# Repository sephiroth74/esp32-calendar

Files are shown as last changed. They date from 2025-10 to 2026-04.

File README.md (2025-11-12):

# ESP32 E-Paper Calendar Display

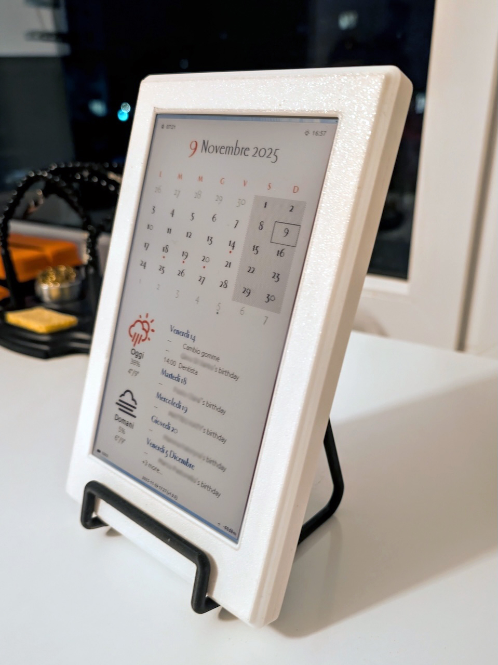
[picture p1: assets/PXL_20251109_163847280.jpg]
Preview


A feature-rich calendar display using ESP32 (S3/C6) and Waveshare/Good Display 7.5" e-paper displays (B/W or 6-color) with dual orientation support, comprehensive error handling, and multiple language support.

**Version 1.9.0** - Timezone fix for recurring events and API improvements!

## What's New in v1.9.0

- 🐛 **WEEKLY Recurring Event Fix**: Fixed 2-day offset in WEEKLY recurring events with COUNT limit
  - Root cause: Mixed use of local timezone and UTC caused date calculation errors
  - Solution: Use GMT/UTC consistently with new `portable_timegm()` helper
  - Test coverage: **240/240 tests passing (100%)**
- 🔧 **Display Manager API Refactoring**: Simplified API by using `time_t` instead of 5 separate date/time parameters
  - `showModernCalendar(events, now, weatherData, ...)` - cleaner signature
  - Date/time components now extracted internally from single `time_t` parameter
  - All orientation-specific methods updated for consistency

See [CHANGELOG.md](CHANGELOG.md) for complete details.

## 3D Model

A .3mf 3d model for the enclosure is available here [assets/esp32-calendar.3mf](assets/esp32-calendar.3mf).

## Features

### Display Features
- **Multi-Display Support**: Works with both B/W and 6-color e-paper displays
- **Dual Orientation Support**: Choose between landscape (800x480) or portrait (480x800) layout
  - **Landscape Mode**: Split-screen with calendar on left, events and weather on right
  - **Portrait Mode**: Calendar on top, weather on left side, events on right
- **Compile-Time Optimization**: Only the selected orientation code is compiled, saving ~6KB flash
- **6-Color Display Enhancements**: Configurable color scheme for visual hierarchy
- **Floyd-Steinberg Dithering**: Weekend cells (25% yellow on color, 10% gray on B/W)
- **Event Indicators**: Small dots in calendar cells with events
- **Smart Event Grouping**: Today, Tomorrow, and upcoming events sections with date headers
- **Weather Display**: Today and tomorrow forecast with icons, temperature, and precipitation
- **Embedded Icons**: High-quality bitmap icons for errors, warnings, and status indicators

### Calendar Features
- **Multiple Calendar Sources**: ICS URLs (Google Calendar, iCloud, Outlook), Google Calendar API, CalDAV
- **Smart Event Filtering**: Shows ALL of today's events (even if passed), plus future events
- **Timezone Support**: Automatic timezone conversion with DST support
- **First Day of Week**: Configurable (Sunday/Monday)
- **24-Hour Time Format**: Optional 24-hour time display for events

### System Features
- **Comprehensive Error Handling**: 40+ error codes with visual feedback and localization
- **Multi-Language Support**: English and Italian (easily extensible)
- **Enhanced Power Management**: Immediate deep sleep after display update
- **Battery Monitoring**: Real-time battery status with accurate LiPo curve
- **WiFi Status**: Connection indicator with RSSI display
- **PSRAM Support**: Utilizes ESP32-S3's PSRAM for large calendar data
- **Debug Mode**: Interactive serial menu for testing all features without WiFi
- **Semantic Versioning**: Built-in version management for OTA updates
- **Button Wake-Up**: Manual refresh via button press (GPIO 2)
- **Weather Integration**: Real-time weather with Open-Meteo API

## Hardware Requirements

- **ESP32 Board**:
  - ESP32-S3 (recommended - includes PSRAM for large calendar data): [Waveshare ESP32-S3 Zero](https://www.waveshare.com/wiki/ESP32-S3-Zero)
  - Minimum 4MB flash, 2MB PSRAM recommended
- **Display Options**:
  - **B/W Display**: Waveshare 7.5" (800x480) - Models: V2, V3, GDEY075T7
  - **6-Color Display**: Good Display 7.5" GDEP073E01 (800x480) - Black, White, Red, Yellow, Orange, Green
- **Display Adapter**:
  - **Despi-C73**: [GoodDisplay Despi-C73](https://www.good-display.com/product/522.html) adapter board for colored display (or the Despi-C02 for the BW variant)
- **Breadboard PCB**:
  - Solderable Breadboard PCB Board [EPLZON PCB](https://www.amazon.com/EPLZON-Solder-able-Breadboard-Electronics-Compatible/dp/B09WZXHMDG?th=1)
- **Battery**:
  - [3.7v 3000mAh Li-ion Battery](https://www.amazon.it/3000mAh-103665-Lithium-Replacement-Bluetooth/dp/B091Y3TW9F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)
- **Optional Components**:
  - Wake-up button (connected to GPIO 2)
  - LiPo battery for portable operation
  - Voltage divider for battery monitoring (GPIO 1)

## Wiring

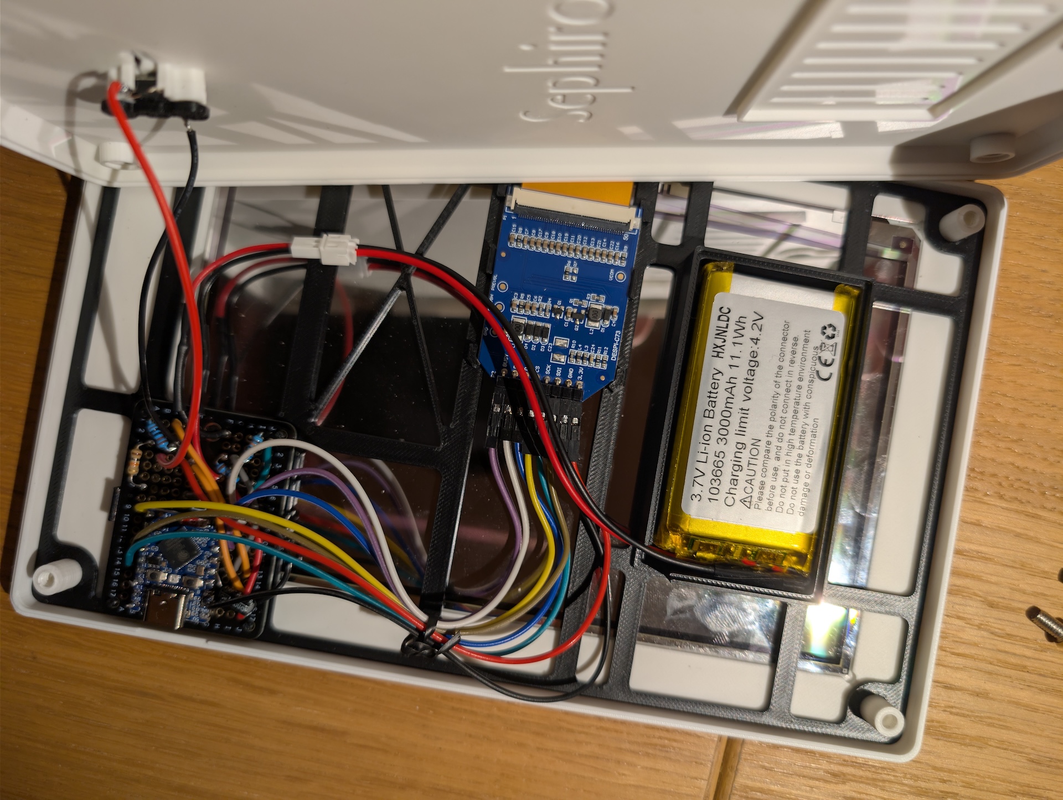
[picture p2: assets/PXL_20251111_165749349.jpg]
Wiring


### ESP32-S3 Connections
| E-Paper | ESP32-S3 | Description |
|---|---|---|
| VCC | 3.3V | Power |
| GND | GND | Ground |
| DIN | GPIO 11  | SPI MOSI |
| CLK | GPIO 12  | SPI Clock |
| CS | GPIO 7 | Chip Select |
| DC | GPIO 5 | Data/Command|
| RST | GPIO 6 | Reset |
| BUSY | GPIO 4 | Busy Signal |

## Configuration

### 1. Initial Setup

Configuration is now managed through LittleFS using a `config.json` file. See the [LittleFS Configuration Guide](platformio/docs/LITTLEFS_CONFIG.md) for details.

For quick setup, edit `include/config.h` with your basic settings:

```cpp
// Location for weather (find at https://www.latlong.net/)
#define LOC_LATITUDE 40.7128    // Example: New York
#define LOC_LONGITUDE -74.0060   // Example: New York
```

### 2. Calendar and Weather Configuration

All runtime configuration is now managed through `data/config.json`. Create this file with your settings:

```json
{
  "wifi": {
    "ssid": "YOUR_WIFI_NETWORK",
    "password": "YOUR_PASSWORD"
  },
  "location": {
    "latitude": 40.7128,
    "longitude": -74.0060,
    "timezone": "America/New_York"
  },
  "calendars": [
    {
      "name": "Personal",
      "url": "https://calendar.google.com/calendar/ical/YOUR_CALENDAR_ID/private.ics",
      "color": "red",
      "enabled": true,
      "days_to_fetch": 30
    },
    {
      "name": "Work",
      "url": "https://outlook.office365.com/owa/calendar/YOUR_CALENDAR_ID/calendar.ics",
      "color": "blue",
      "enabled": true,
      "days_to_fetch": 30
    }
  ],
  "display": {
    "update_hour": 5,
    "language": "en"
  }
}
```

**How to get ICS URLs:**
- **Google Calendar**: Settings → Calendar → Integrate → Secret address in iCal format
- **iCloud**: Calendar app → Share Calendar → Public Calendar → Copy link
- **Outlook**: Settings → View all Outlook settings → Calendar → Shared calendars → Publish a calendar → Copy ICS link

**Upload configuration to device:**
```bash
pio run -t uploadfs
```

This uploads the `data/` folder (including `config.json`) to the ESP32's LittleFS filesystem.

### 3. Display Settings

Edit `include/config.h` for display type and orientation:

```cpp
// Display Type Selection
// #define DISP_TYPE_BW   // Uncomment for B/W display
#define DISP_TYPE_6C      // Uncomment for 6-color display

// Display Orientation
#define LANDSCAPE 0       // 800x480 - Calendar left, events right
#define PORTRAIT 1        // 480x800 - Calendar top, events/weather bottom
#define DISPLAY_ORIENTATION LANDSCAPE  // Change to PORTRAIT for vertical layout

// Time & Locale (can be overridden in config.json)
#define TIME_FORMAT_24H true          // true for 24-hour, false for 12-hour
#define FIRST_DAY_OF_WEEK 1           // 0=Sunday, 1=Monday
#define MAX_EVENTS_TO_SHOW 10         // Maximum events on display

// Color Customization (6-color displays only)
#ifdef DISP_TYPE_6C
    #define COLOR_CALENDAR_TODAY_TEXT      GxEPD_RED      // Today's date number
    #define COLOR_CALENDAR_TODAY_BORDER    GxEPD_RED      // Today's border
    #define COLOR_CALENDAR_OUTSIDE_MONTH   GxEPD_GREEN    // Previous/next month days
    #define COLOR_CALENDAR_WEEKEND_BG      GxEPD_YELLOW   // Weekend background (25% dithered)
    #define COLOR_CALENDAR_DAY_LABELS      GxEPD_RED      // Day labels (M, T, W...)
    #define COLOR_EVENT_TODAY_HEADER       GxEPD_RED      // "Today" header
    #define COLOR_EVENT_TOMORROW_HEADER    GxEPD_ORANGE   // "Tomorrow" header
    #define COLOR_EVENT_OTHER_HEADER       GxEPD_GREEN    // Other date headers
    #define COLOR_WEATHER_ICON            GxEPD_RED       // Weather icon
    #define COLOR_HEADER_DAY_NUMBER       GxEPD_RED       // Large day number
#endif
```

## Building and Uploading

### Prerequisites
1. Install PlatformIO (VS Code extension or CLI)
2. Configure your settings in `config.json` (see Configuration section above)
3. Connect your ESP32 board via USB

### Standard Build
1. Open the project folder
2. Select your board environment in `platformio.ini`:
   - `esp32-s3-devkitm-1` for ESP32-S3 boards
   - Add your own environment for other boards
3. Build the project:
   ```bash
   pio run -e esp32-s3-devkitm-1
   ```
4. Upload to your board:
   ```bash
   pio run -t upload -e esp32-s3-devkitm-1
   ```
5. Monitor serial output:
   ```bash
   pio device monitor
   ```

### Debug Mode
Enable debug mode to test all features without WiFi or calendar configuration:

1. Edit `platformio.ini` and add/ensure this build flag:
   ```ini
   build_flags =
       -DDEBUG_DISPLAY=1
   ```

2. Build and upload:
   ```bash
   pio run -t upload -e esp32-s3-devkitm-1
   ```

3. Open serial monitor (115200 baud) and use the interactive menu:
   - `1` - Test Monthly Calendar View
   - `2` - Test Event List
   - `3` - Test Full Screen Errors
   - `4` - Test WiFi Connection
   - `5` - Test Icon Display
   - `6` - Test Battery Status
   - `7` - Test Calendar Fetch
   - `8` - Test Error Levels
   - `9` - Test Dithering Patterns
   - `10` - Test Time Display
   - `11` - Clear Display
   - `12` - Full Calendar Demo
   - `h` - Show menu

## Power Consumption

With optimized once-daily updates (v1.3.0):
- **Active**: ~80mA (during WiFi/display update, ~20-30 seconds)
- **Deep Sleep**: ~10µA (23+ hours per day)
- **Average**: ~0.2mA (with once-daily updates)
- **Battery Life**: 8-12 months on 2000mAh battery

Power-saving features:
- **Once-daily update** at configured hour (DAY_START_HOUR)
- **Smart error recovery**: Shorter retry intervals only on errors
- **Battery protection**: No wake-up when battery critical
- **Immediate deep sleep** after display update
- **Manual refresh** available via button press

## Troubleshooting

### Configuration not loading
- **Solution**: Upload your `config.json` file to LittleFS:
  ```bash
  pio run -t uploadfs
  ```
- See [LittleFS Configuration Guide](platformio/docs/LITTLEFS_CONFIG.md) for details

### Display not updating
- Check wiring connections
- Verify SPI pins in config.h match your wiring
- Try the display test function in setup()

### WiFi connection fails
- Verify SSID and password in `data/config.json`
- Upload filesystem with `pio run -t uploadfs`
- Check if 2.4GHz WiFi is enabled (ESP32 doesn't support 5GHz)
- Increase connection timeout if needed

### No calendar events showing
- Verify your calendar URL is accessible
- Check if the URL requires authentication
- For ICS URLs, make sure they're publicly accessible
- Check serial monitor for error messages

### Time is incorrect
- Verify timezone setting in `data/config.json` (e.g., "America/New_York", "Europe/Rome")
- Upload filesystem with `pio run -t uploadfs`
- Check that NTP servers are accessible
- System automatically handles DST based on timezone

## Display Layout

The display supports two orientations, configured via `DISPLAY_ORIENTATION` in `config.h`:

### Landscape Mode (800x480) - Default

**Left Side - Month Calendar (400px)**
- **Header**: Large day number and month/year, centered with sunrise/sunset times
- **Calendar Grid**:
  - Day of week labels (localized, red on color displays)
  - 6-week calendar grid with smart visual hierarchy
  - Current day with colored border (red on color displays)
  - Event indicators (dots) in calendar cells
  - Weekend cells with 25% yellow (color) or 10% gray (B/W) background
  - Previous/next month days in green (color) or 20% gray (B/W)

**Right Side - Events & Weather (400px)**
- **Event Sections** (top 340px):
  - "Today" section with ALL of today's events (even if passed)
  - "Tomorrow" section
  - Smart date grouping for future events
  - Event details: time (12/24h format), title
  - Up to 10 events displayed with "+N more" indicator
- **Weather Display** (bottom 100px):
  - Side-by-side today and tomorrow forecast
  - 64x64 weather icons (red on color displays)
  - Temperature range and precipitation probability

**Status Bar** (bottom, full width):
- WiFi status with RSSI (left)
- Battery percentage (left)
- Version info (right)

### Portrait Mode (480x800) - Optional

**Top Section - Header & Calendar (410px)**
- **Header**: Compact centered day number and month/year
- **Calendar Grid**: Full-width calendar (7 columns × 480px)
  - Compact 35px cell height for space efficiency
  - Same visual features as landscape (borders, dots, weekend highlighting)

**Bottom Section - Events & Weather (340px)**
- **Left Panel - Weather (180px)**:
  - Vertical stacked layout
  - Today and tomorrow sections
  - 48x48 weather icons
  - Temperature and precipitation probability
- **Right Panel - Events (290px)**:
  - Event list with smart date grouping
  - Up to 8 events displayed
  - Time and title per line
  - "+N more" indicator if needed

**Status Bar** (bottom, full width):
- Same layout as landscape mode

### Switching Orientations

Change the `DISPLAY_ORIENTATION` constant in `include/config.h`:

```cpp
#define DISPLAY_ORIENTATION LANDSCAPE  // For 800x480 horizontal
// or
#define DISPLAY_ORIENTATION PORTRAIT   // For 480x800 vertical
```

The display rotation and layout are automatically configured at compile-time. Only the code for the selected orientation is compiled, saving ~6KB flash memory.

## Error Handling

The system includes comprehensive error handling with visual feedback:

### Error Levels
- **INFO**: Informational messages
- **WARNING**: Non-critical issues (system continues)
- **ERROR**: Significant problems (may retry)
- **CRITICAL**: System failure (requires intervention)

### Error Categories
- **WiFi Errors** (100-199): Connection failures, authentication issues
- **Calendar Errors** (200-299): Fetch failures, parsing errors
- **Display Errors** (300-399): Hardware issues, refresh failures
- **System Errors** (400-499): Memory, filesystem problems
- **Battery Errors** (500-599): Low battery, charging issues
- **Time Errors** (600-699): NTP sync failures
- **Configuration Errors** (700-799): Invalid settings
- **Network Errors** (800-899): HTTP/HTTPS issues
- **Parsing Errors** (900-999): Data format problems

## Localization

Add new languages by creating a header file in `include/lang/`:

```cpp
// include/lang/es.h (Spanish example)
#define LOC_TODAY "Hoy"
#define LOC_TOMORROW "Mañana"
#define LOC_NO_EVENTS "Sin eventos"
// ... add all string translations
```

Then update `include/localization.h` to include your language file.

## Documentation

- **[Architecture Guide](platformio/docs/ARCHITECTURE.md)** - Comprehensive system architecture, design decisions, and data flow
- **[Changelog](CHANGELOG.md)** - Version history and release notes

## Project Structure

```
platformio/
├── include/
│   ├── config.h                   # User configuration (orientation, colors, etc.)
│   ├── display_manager.h          # Display control with orientation-specific declarations
│   ├── calendar_client.h          # Calendar fetching
│   ├── error_manager.h            # Error handling
│   ├── localization.h             # Language selection
│   ├── version.h                  # Version management
│   └── lang/                      # Language files
│       ├── en.h                   # English
│       └── it.h                   # Italian
├── src/
│   ├── main.cpp                   # Main program
│   ├── debug.cpp                  # Debug mode (orientation-aware)
│   ├── display_manager.cpp        # Core display + orientation dispatcher
│   ├── display_landscape.cpp      # Landscape layout (compiled only if LANDSCAPE)
│   ├── display_portrait.cpp       # Portrait layout (compiled only if PORTRAIT)
│   ├── display_calendar_helpers.cpp # Shared calendar utilities
│   ├── display_shared.cpp         # Shared display functions (status bar, errors)
│   ├── calendar_client.cpp        # Calendar parsing
│   ├── error_manager.cpp          # Error handling
│   └── wifi_manager.cpp           # WiFi management
├── data/
│   └── config.json                # Configuration file (uploaded to LittleFS)
├── lib/
│   └── esp32-calendar-assets/     # Icons and fonts
├── docs/
│   ├── ARCHITECTURE.md            # System architecture and design
│   ├── LITTLEFS_CONFIG.md         # LittleFS configuration guide
│   └── CALENDAR_SPECS.md          # ICS format specification
└── platformio.ini                 # Build configuration
```

### Display Module Organization (Compile-Time Optimized)

The display code is organized for maximum efficiency:

- **`display_manager.cpp`**: Core functions + orientation dispatcher (always compiled)
- **`display_landscape.cpp`**: Complete landscape implementation (compiled only when `DISPLAY_ORIENTATION == LANDSCAPE`)
- **`display_portrait.cpp`**: Complete portrait implementation (compiled only when `DISPLAY_ORIENTATION == PORTRAIT`)
- **`display_calendar_helpers.cpp`**: Shared calendar utilities used by both orientations (always compiled)
- **`display_shared.cpp`**: Shared functions like status bar and error screens (always compiled)

This architecture ensures that only the code for the selected orientation is included in the final binary, reducing flash usage by ~6KB.

## Memory Usage

Typical resource usage (ESP32-S3 with 4MB flash):

- **Flash (Landscape)**: ~1.34MB (44.4% of 3.0MB available)
- **Flash (Portrait)**: ~1.33MB (44.2% of 3.0MB available) - *6KB smaller due to compile-time optimization*
- **RAM**: ~112KB (34.2% of 320KB)
- **PSRAM**: Used for large calendar data when available

## Known Issues

1. **ICS Timezone Parsing**: Events with UTC timestamps need manual timezone adjustment
2. **Event Limits**: Display limited to MAX_EVENTS_TO_SHOW (default: 10)

## License

This project is released under the GNU General Public License v3.0 (GPLv3).

Why GPLv3?

This project incorporates source code from an external project, lmarzen/esp32-weather-epd, which is licensed under the GPLv3.

Due to the "strong copyleft" nature of the GPLv3, any work that includes or is derived from GPLv3-licensed code must also be licensed under the GPLv3. This license is intended to guarantee users the freedom to share and change all versions of the software.

## Contributing

Contributions are welcome! Please submit pull requests or open issues for bugs and feature requests.

## Acknowledgments

- GxEPD2 library for e-paper display support
- Adafruit GFX library for graphics primitives
- ArduinoJson for JSON parsing
- ESP32 community for platform support

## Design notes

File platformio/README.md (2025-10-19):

# ESP32 E-Paper Calendar Display

A feature-rich calendar display using ESP32 (S3/C6) and Waveshare/Good Display 7.5" e-paper displays (B/W or 6-color) with split-screen layout, comprehensive error handling, and multiple language support.

**Version 1.3.0** - Once-daily updates, intelligent error recovery, and secure configuration!

## What's New in v1.3.0

- 📅 **Once-Daily Updates**: Calendar refreshes once per day for maximum battery life
- 🔐 **Secure Configuration**: WiFi credentials and location data now in separate, git-ignored file
- 🔄 **Smart Error Recovery**: Automatic retry with intelligent intervals based on error type
- 🔋 **Critical Battery Handling**: No wake on low battery to prevent damage
- 🛠️ **Button Noise Fix**: Enhanced filtering and hardware recommendations for stable operation
- 📝 **Improved Documentation**: Comprehensive setup guide and configuration examples

See [CHANGELOG.md](CHANGELOG.md) for complete details.

## Features

### Display Features
- **Multi-Display Support**: Works with both B/W and 6-color e-paper displays
- **Split-Screen Layout**: Month calendar on left, event list on right
- **6-Color Display Enhancements**: Configurable color scheme for visual hierarchy
- **Floyd-Steinberg Dithering**: Weekend cells (25% yellow on color, 10% gray on B/W)
- **Event Indicators**: Small dots in calendar cells with events
- **Smart Event Grouping**: Today, Tomorrow, and upcoming events sections with date headers
- **Large Weather Icon**: 96x96 pixel weather display with current conditions
- **Embedded Icons**: High-quality bitmap icons for errors, warnings, and status indicators

### Calendar Features
- **Multiple Calendar Sources**: ICS URLs (Google Calendar, iCloud, Outlook), Google Calendar API, CalDAV
- **Smart Event Filtering**: Shows ALL of today's events (even if passed), plus future events
- **Timezone Support**: Automatic timezone conversion with DST support
- **First Day of Week**: Configurable (Sunday/Monday)
- **24-Hour Time Format**: Optional 24-hour time display for events

### System Features
- **Comprehensive Error Handling**: 40+ error codes with visual feedback and localization
- **Multi-Language Support**: English and Italian (easily extensible)
- **Enhanced Power Management**: Immediate deep sleep after display update
- **Battery Monitoring**: Real-time battery status with accurate LiPo curve
- **WiFi Status**: Connection indicator with RSSI display
- **PSRAM Support**: Utilizes ESP32-S3's PSRAM for large calendar data
- **Debug Mode**: Interactive serial menu for testing all features without WiFi
- **Semantic Versioning**: Built-in version management for OTA updates
- **Button Wake-Up**: Manual refresh via button press (GPIO 2)
- **Weather Integration**: Real-time weather with Open-Meteo API

## Hardware Requirements

- **ESP32 Board**:
  - ESP32-S3 (recommended - includes PSRAM for large calendar data)
  - ESP32-C6 (supported)
  - Minimum 4MB flash, 2MB PSRAM recommended
- **Display Options**:
  - **B/W Display**: Waveshare 7.5" (800x480) - Models: V2, V3, GDEY075T7
  - **6-Color Display**: Good Display 7.5" GDEP073E01 (800x480) - Black, White, Red, Yellow, Orange, Green
- **Optional Components**:
  - Wake-up button (connected to GPIO 2)
  - LiPo battery for portable operation
  - Voltage divider for battery monitoring (GPIO 1)

## Wiring

### ESP32-S3 Connections
| E-Paper | ESP32-S3 | Description |
|---|---|---|
| VCC | 3.3V | Power |
| GND | GND | Ground |
| DIN | GPIO 11  | SPI MOSI |
| CLK | GPIO 12  | SPI Clock |
| CS | GPIO 7 | Chip Select |
| DC | GPIO 5 | Data/Command|
| RST | GPIO 6 | Reset |
| BUSY | GPIO 4 | Busy Signal |

### ESP32-C6 Connections
| E-Paper | ESP32-C6 | Description |
|---|---|---|
| VCC | 3.3V | Power |
| GND | GND | Ground |
| DIN | GPIO 10  | SPI MOSI |
| CLK | GPIO 8 | SPI Clock |
| CS | GPIO 7 | Chip Select |
| DC | GPIO 5 | Data/Command|
| RST | GPIO 6 | Reset |
| BUSY | GPIO 4 | Busy Signal |

## Configuration

### 🔐 Initial Setup - IMPORTANT!

Before compiling, you must create your local configuration file:

```bash
cd include/
cp config.local.example config.local
```

Edit `include/config.local` with your WiFi credentials and location:

```cpp
// WiFi credentials
#define WIFI_SSID "YOUR_WIFI_NETWORK"
#define WIFI_PASSWORD "YOUR_PASSWORD"

// Location for weather (find at https://www.latlong.net/)
#define LOC_LATITUDE 40.7128    // Example: New York
#define LOC_LONGITUDE -74.0060   // Example: New York
```

**Note:** `config.local` is git-ignored, so your credentials stay private!

### 2. Calendar Source

Edit `include/config.h` to configure your calendar source:

Choose one of three options:

#### Option A: ICS URL (Simplest)
Most calendar services provide an ICS URL for read-only access:

```cpp
#define CALENDAR_TYPE "ICS"
#define ICS_CALENDAR_URL "YOUR_CALENDAR_ICS_URL"
```

**How to get ICS URLs:**
- **Google Calendar**: Settings → Calendar → Integrate → Secret address in iCal format
- **iCloud**: Calendar app → Share Calendar → Public Calendar → Copy link
- **Outlook**: Settings → View all Outlook settings → Calendar → Shared calendars → Publish a calendar → Copy ICS link

#### Option B: Google Calendar API
```cpp
#define CALENDAR_TYPE "GOOGLE"
#define GOOGLE_CALENDAR_ID "primary"
#define GOOGLE_API_KEY "YOUR_API_KEY"
// Additional OAuth tokens required
```

#### Option C: CalDAV
```cpp
#define CALENDAR_TYPE "CALDAV"
#define CALDAV_SERVER "https://caldav.icloud.com"
#define CALDAV_USERNAME "YOUR_USERNAME"
#define CALDAV_PASSWORD "YOUR_APP_PASSWORD"
```

### 3. Display Settings

Edit `include/config.h` for display and timing preferences:

```cpp
// Display Type Selection
// #define DISP_TYPE_BW   // Uncomment for B/W display
#define DISP_TYPE_6C      // Uncomment for 6-color display

// Update Settings
#define DAY_START_HOUR 5              // Daily update hour (5 = 5:00 AM)
#define WIFI_ERROR_RETRY_MINUTES 60   // Retry WiFi errors after 1 hour
#define CALENDAR_ERROR_RETRY_MINUTES 120 // Retry calendar errors after 2 hours

// Time & Locale
#define TIMEZONE "CET-1CEST,M3.5.0,M10.5.0"  // Timezone string with DST
#define TIME_FORMAT_24H true          // true for 24-hour, false for 12-hour
#define FIRST_DAY_OF_WEEK 1           // 0=Sunday, 1=Monday
#define DISPLAY_LANGUAGE 0            // 0=English, 4=Italian

// Event Display
#define DAYS_TO_FETCH 30              // Event range in days
#define MAX_EVENTS_TO_SHOW 10         // Maximum events on display

// Color Customization (6-color displays only)
#ifdef DISP_TYPE_6C
    #define COLOR_CALENDAR_TODAY_TEXT      GxEPD_RED      // Today's date number
    #define COLOR_CALENDAR_TODAY_BORDER    GxEPD_RED      // Today's border
    #define COLOR_CALENDAR_OUTSIDE_MONTH   GxEPD_GREEN    // Previous/next month days
    #define COLOR_CALENDAR_WEEKEND_BG      GxEPD_YELLOW   // Weekend background (25% dithered)
    #define COLOR_CALENDAR_DAY_LABELS      GxEPD_RED      // Day labels (M, T, W...)
    #define COLOR_EVENT_TODAY_HEADER       GxEPD_RED      // "Today" header
    #define COLOR_EVENT_TOMORROW_HEADER    GxEPD_ORANGE   // "Tomorrow" header
    #define COLOR_EVENT_OTHER_HEADER       GxEPD_GREEN    // Other date headers
    #define COLOR_WEATHER_ICON            GxEPD_RED       // Weather icon
    #define COLOR_HEADER_DAY_NUMBER       GxEPD_RED       // Large day number
#endif
```

## Building and Uploading

### Prerequisites
1. Install PlatformIO (VS Code extension or CLI)
2. **Create your config.local file** (see Configuration section above)
3. Connect your ESP32 board via USB

### Standard Build
1. Open the project folder
2. Select your board environment in `platformio.ini`:
   - `esp32-s3-devkitc-1` for ESP32-S3 boards
   - Add your own environment for other boards
3. Build the project:
   ```bash
   pio run -e esp32-s3-devkitc-1
   ```
4. Upload to your board:
   ```bash
   pio run -t upload -e esp32-s3-devkitc-1
   ```
5. Monitor serial output:
   ```bash
   pio device monitor
   ```

### Debug Mode
Enable debug mode to test all features without WiFi or calendar configuration:

1. Edit `platformio.ini` and add/ensure this build flag:
   ```ini
   build_flags =
       -DDEBUG_DISPLAY=1
   ```

2. Build and upload:
   ```bash
   pio run -t upload -e esp32-s3-devkitc-1
   ```

3. Open serial monitor (115200 baud) and use the interactive menu:
   - `1` - Test Monthly Calendar View
   - `2` - Test Event List
   - `3` - Test Full Screen Errors
   - `4` - Test WiFi Connection
   - `5` - Test Icon Display
   - `6` - Test Battery Status
   - `7` - Test Calendar Fetch
   - `8` - Test Error Levels
   - `9` - Test Dithering Patterns
   - `10` - Test Time Display
   - `11` - Clear Display
   - `12` - Full Calendar Demo
   - `h` - Show menu

## Power Consumption

With optimized once-daily updates (v1.3.0):
- **Active**: ~80mA (during WiFi/display update, ~20-30 seconds)
- **Deep Sleep**: ~10µA (23+ hours per day)
- **Average**: ~0.2mA (with once-daily updates)
- **Battery Life**: 8-12 months on 2000mAh battery

Power-saving features:
- **Once-daily update** at configured hour (DAY_START_HOUR)
- **Smart error recovery**: Shorter retry intervals only on errors
- **Battery protection**: No wake-up when battery critical
- **Immediate deep sleep** after display update
- **Manual refresh** available via button press

## Troubleshooting

### Compilation error: config.local not found
- **Solution**: You need to create the local configuration file:
  ```bash
  cd include/
  cp config.local.example config.local
  # Edit config.local with your WiFi credentials
  ```

### Display not updating
- Check wiring connections
- Verify SPI pins in config.h match your wiring
- Try the display test function in setup()

### WiFi connection fails
- Verify SSID and password in `include/config.local` (not config.h)
- Check if 2.4GHz WiFi is enabled (ESP32 doesn't support 5GHz)
- Increase connection timeout if needed
- Ensure `config.local` exists (copy from `config.local.example`)

### No calendar events showing
- Verify your calendar URL is accessible
- Check if the URL requires authentication
- For ICS URLs, make sure they're publicly accessible
- Check serial monitor for error messages

### Time is incorrect
- Verify TIMEZONE string in config.h (e.g., "CET-1CEST,M3.5.0,M10.5.0" for Central Europe)
- Check that NTP servers are accessible
- System automatically handles DST based on timezone string

## Display Layout

The 800x480 display is divided into two main sections:

### Left Side - Month Calendar (400px)
- **Header**: Large day number (32pt) and month/year (26pt), centered
- **Calendar Grid**:
  - Day of week labels (localized, red on color displays)
  - 6-week calendar grid with smart visual hierarchy
  - Current day with colored border (red on color displays)
  - Event indicators (dots) in calendar cells
  - Weekend cells with 25% yellow (color) or 10% gray (B/W) background
  - Previous/next month days in green (color) or 20% gray (B/W)

### Right Side - Event List (400px)
- **Event Sections**:
  - "Oggi/Today" section with ALL of today's events (even if passed)
  - "Domani/Tomorrow" section
  - Smart date grouping for future events
  - Event details: time (12/24h format), title with word-wrap
  - Dynamic event limit with "+N more events" indicator
- **Weather Display** (bottom):
  - Large 96x96 weather icon (red on color displays)
  - Current temperature range
  - Sunrise/sunset times with icons
  - 7-day hourly forecast

### Status Bar (bottom)
- Current date/time (center)
- Version info (center)
- WiFi status with RSSI (right)
- Battery percentage (left)

## Error Handling

The system includes comprehensive error handling with visual feedback:

### Error Levels
- **INFO**: Informational messages
- **WARNING**: Non-critical issues (system continues)
- **ERROR**: Significant problems (may retry)
- **CRITICAL**: System failure (requires intervention)

### Error Categories
- **WiFi Errors** (100-199): Connection failures, authentication issues
- **Calendar Errors** (200-299): Fetch failures, parsing errors
- **Display Errors** (300-399): Hardware issues, refresh failures
- **System Errors** (400-499): Memory, filesystem problems
- **Battery Errors** (500-599): Low battery, charging issues
- **Time Errors** (600-699): NTP sync failures
- **Configuration Errors** (700-799): Invalid settings
- **Network Errors** (800-899): HTTP/HTTPS issues
- **Parsing Errors** (900-999): Data format problems

## Localization

Add new languages by creating a header file in `include/lang/`:

```cpp
// include/lang/es.h (Spanish example)
#define LOC_TODAY "Hoy"
#define LOC_TOMORROW "Mañana"
#define LOC_NO_EVENTS "Sin eventos"
// ... add all string translations
```

Then update `include/localization.h` to include your language file.

## Project Structure

```
platformio/
├── include/
│   ├── config.h              # User configuration
│   ├── display_manager.h      # Display control
│   ├── calendar_client.h      # Calendar fetching
│   ├── error_manager.h        # Error handling
│   ├── localization.h         # Language selection
│   ├── version.h              # Version management
│   └── lang/                  # Language files
│       ├── en.h               # English
│       └── it.h               # Italian
├── src/
│   ├── main.cpp               # Main program
│   ├── debug.cpp              # Debug mode
│   ├── display_manager.cpp    # Display implementation
│   ├── calendar_client.cpp    # Calendar parsing
│   ├── error_manager.cpp      # Error handling
│   └── wifi_manager.cpp       # WiFi management
├── lib/
│   └── esp32-calendar-assets/ # Icons and fonts
└── platformio.ini             # Build configuration
```

## Memory Usage

Typical resource usage (ESP32-S3 with 4MB flash):

- **Flash**: ~1.8MB (57% of 3.1MB available)
- **RAM**: ~95KB (29% of 320KB)
- **PSRAM**: Used for large calendar data when available

## Version Information

Current version: **1.0.0**

The project uses semantic versioning (MAJOR.MINOR.PATCH):
- **MAJOR**: Incompatible API changes
- **MINOR**: Backwards-compatible functionality additions
- **PATCH**: Backwards-compatible bug fixes

Version details are in `include/version.h` and displayed on serial startup.

## Known Issues

1. **ICS Timezone Parsing**: Events with UTC timestamps need manual timezone adjustment
2. **Event Limits**: Display limited to MAX_EVENTS_TO_SHOW (default: 10)
3. **Deep Sleep**: RTC time drift may occur over extended periods

## License

This project is open source. Feel free to modify and distribute.

## Contributing

Contributions are welcome! Please submit pull requests or open issues for bugs and feature requests.

## Acknowledgments

- GxEPD2 library for e-paper display support
- Adafruit GFX library for graphics primitives
- ArduinoJson for JSON parsing
- ESP32 community for platform support

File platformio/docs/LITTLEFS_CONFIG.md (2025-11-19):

# Configuration Guide - ESP32 E-Paper Calendar

This document explains how to configure the ESP32 E-Paper Calendar using the LittleFS filesystem configuration system.

## Overview

The ESP32 Calendar loads all configuration from a JSON file stored in the LittleFS filesystem. This approach provides:

- ✅ **No recompilation needed** - Change settings without rebuilding firmware
- ✅ **Secure credentials** - WiFi passwords stay out of source control
- ✅ **Easy deployment** - Configure multiple devices with different settings
- ✅ **Simple updates** - Change configuration via filesystem upload

## Configuration File Structure

The configuration is stored in `/data/config.json` with the following structure:

```json
{
  "wifi": {
    "ssid": "YOUR_WIFI_SSID",
    "password": "YOUR_WIFI_PASSWORD"
  },
  "location": {
    "latitude": 40.7128,
    "longitude": -74.0060,
    "name": "New York"
  },
  "calendar": {
    "type": "ics",
    "url": "https://calendar.google.com/calendar/ical/YOUR_CALENDAR_ID/public/basic.ics",
    "days_to_fetch": 30
  },
  "display": {
    "timezone": "EST5EDT,M3.2.0,M11.1.0",
    "update_hours": [6, 12, 18]
  }
}
```

## Setup Instructions

### 1. Prepare Configuration File

1. Copy the example configuration:
   ```bash
   cp data/config.json.example data/config.json
   ```

2. Edit `data/config.json` with your settings:
   - **WiFi credentials**: Your network SSID and password
   - **Location**: Latitude/longitude for weather data
   - **Calendar URL**: Your ICS calendar feed URL
   - **Timezone**: Your timezone string (see examples below)

### 2. Upload Filesystem

Upload the configuration to the ESP32's filesystem:

```bash
pio run -t uploadfs -e esp32-s3-devkitc-1
```

This command will:
- Create a LittleFS image from the `data/` directory
- Upload it to the ESP32's flash memory
- The configuration will persist across power cycles

### 3. Upload Firmware

After uploading the filesystem, upload the main firmware:

```bash
pio run -t upload -e esp32-s3-devkitc-1
```

### 4. Monitor Output

Check that configuration loaded correctly:

```bash
pio device monitor
```

You should see output like:
```
LittleFS mounted successfully
Configuration loaded successfully from LittleFS
=== Current Configuration ===
WiFi:
  SSID: YourNetwork
  Password: ********
Location:
  Name: New York
  Latitude: 40.712800
  Longitude: -74.006000
```

## Testing Configuration Reset

The firmware includes a test mode for configuration reset:

### Enable Test Mode

In `include/config.h`, ensure:
```c
#define DISABLE_DEEP_SLEEP true
```

This keeps the device awake to monitor button presses.

### Reset Configuration

1. Hold the button (GPIO 2) for 3 seconds
2. The display will show "Configuration Reset"
3. Device will restart
4. You'll need to upload a new config.json

### Production Mode

For normal operation, disable test mode:
```c
#define DISABLE_DEEP_SLEEP false
```

The device will then enter deep sleep between updates to save battery.

## Timezone Examples

Common timezone strings for the `display.timezone` field:

- **US Eastern**: `"EST5EDT,M3.2.0,M11.1.0"`
- **US Pacific**: `"PST8PDT,M3.2.0,M11.1.0"`
- **US Central**: `"CST6CDT,M3.2.0,M11.1.0"`
- **UK**: `"GMT0BST,M3.5.0,M10.5.0"`
- **Central Europe**: `"CET-1CEST,M3.5.0,M10.5.0"`
- **Japan**: `"JST-9"`
- **Australia Sydney**: `"AEST-10AEDT,M10.1.0,M4.1.0"`

## Display Configuration

### Update Hours

The `update_hours` field specifies when the device should wake up and refresh the display. You can configure up to 6 update times per day:

```json
{
  "display": {
    "timezone": "CET-1CEST,M3.5.0,M10.5.0",
    "update_hours": [6, 12, 18]
  }
}
```

**Features:**
- Supports up to 6 update times (hours 0-23)
- Automatically removes duplicates and sorts in ascending order
- Falls back to default (5 AM) if empty or invalid
- Backward compatible with legacy `update_hour` (single value)

**Examples:**
- `[6, 12, 18]` - Update at 6 AM, 12 PM, and 6 PM
- `[8]` - Update once per day at 8 AM
- `[0, 6, 12, 18]` - Update four times daily

**Validation:**
- Invalid values (< 0 or > 23) are ignored
- Duplicates are automatically removed
- If more than 6 values, only first 6 are used
- Empty array uses default (5 AM)

### Battery Display

Control whether battery voltage is shown in the status bar using the compile-time constant in `include/config.h`:

```c
#define DISPLAY_BATTERY_SHOW_MILLIVOLTS true  // Show voltage with percentage
```

When enabled, battery status shows as: `85% (4200mV)`
When disabled: `85%`

## Google Calendar URL

To get your Google Calendar ICS URL:

1. Open Google Calendar
2. Go to Settings → Settings for my calendars
3. Select your calendar
4. Scroll to "Integrate calendar"
5. Copy the "Secret address in iCal format"
6. Use this URL in the `calendar.url` field

## Troubleshooting

### Configuration Not Loading

If you see "Configuration Missing" on the display:

1. Verify config.json exists in the data/ directory
2. Check that WiFi credentials are set (not empty)
3. Re-upload filesystem: `pio run -t uploadfs`
4. Monitor serial output for detailed error messages

### WiFi Connection Failed

1. Verify SSID and password are correct
2. Check that the network is 2.4GHz (ESP32 doesn't support 5GHz)
3. Ensure the device is within range

### Filesystem Upload Failed

If `uploadfs` fails:

1. Make sure the device is connected
2. Try erasing flash first: `pio run -t erase`
3. Then upload filesystem again

## File Locations

- **Configuration file**: `data/config.json` (git-ignored)
- **Example template**: `data/config.json.example` (in repository)
- **Configuration class**: `src/littlefs_config.cpp`
- **Test settings**: `include/config.h`

## Security Notes

- The `data/config.json` file is in `.gitignore` to prevent committing credentials
- Always use `config.json.example` as a template
- Never commit actual WiFi passwords or API keys
- The configuration is stored in plain text on the device's flash memory

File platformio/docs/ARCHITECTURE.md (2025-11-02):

# ESP32 Calendar System Architecture

**Version:** 1.7.7
**Last Updated:** 2025-01-02
**Platform:** ESP32-S3 with 7.5" E-Paper Display

## Table of Contents

1. [Overview](#overview)
2. [System Architecture](#system-architecture)
3. [Data Flow](#data-flow)
4. [Core Components](#core-components)
5. [Storage Strategy](#storage-strategy)
6. [Network & Caching](#network--caching)
7. [Display Pipeline](#display-pipeline)
8. [Configuration System](#configuration-system)
9. [Key Design Decisions](#key-design-decisions)

---

## Overview

This is a low-power ESP32-based calendar display that fetches events from multiple ICS calendar feeds, displays them on a 7.5" e-paper screen, and uses deep sleep to conserve battery. The system prioritizes reliability, efficiency, and graceful degradation.

### Key Features

- **Stream Parsing**: Parses ICS files directly from HTTP without storing raw data
- **Binary Event Cache**: Stores processed events (~200 bytes each) for offline fallback
- **Multi-Calendar Support**: Up to 3 calendars with different colors and settings
- **Holiday Support**: Special rendering for holiday calendars
- **Weather Integration**: Open-Meteo API for weather forecasts
- **Battery Monitoring**: MAX17048 fuel gauge integration
- **Deep Sleep**: Wakes daily at configured time or on button press

---

## System Architecture

```
┌─────────────────────────────────────────────────────────────────┐
│                         ESP32-S3 Main                            │
├─────────────────────────────────────────────────────────────────┤
│                                                                   │
│  ┌──────────────┐  ┌──────────────┐  ┌──────────────┐          │
│  │ WiFiManager  │  │CalendarManager│  │WeatherClient │          │
│  └──────┬───────┘  └──────┬───────┘  └──────┬───────┘          │
│         │                  │                  │                   │
│         ├──────────────────┼──────────────────┘                  │
│         │                  │                                      │
│  ┌──────▼──────────────────▼──────────────┐                      │
│  │      CalendarWrapper (per calendar)     │                      │
│  │  ┌────────────────────────────────────┐ │                      │
│  │  │   CalendarStreamParser             │ │                      │
│  │  │   ┌─────────────┐ ┌──────────────┐│ │                      │
│  │  │   │CalendarFetcher│ EventCache   ││ │                      │
│  │  │   └─────────────┘ └──────────────┘│ │                      │
│  │  └────────────────────────────────────┘ │                      │
│  └─────────────────────────────────────────┘                      │
│         │                                                          │
│  ┌──────▼──────────────────────────────────────┐                 │
│  │           DisplayManager                     │                 │
│  │  ┌───────────────────────────────────────┐  │                 │
│  │  │  Header │ Month View │ Events │ Weather│ │                 │
│  │  └───────────────────────────────────────┘  │                 │
│  └──────────────┬───────────────────────────────┘                 │
│                 │                                                  │
│  ┌──────────────▼──────────────┐                                  │
│  │    GxEPD2 (7.5" Display)    │                                  │
│  └─────────────────────────────┘                                  │
│                                                                   │
│  ┌─────────────┐  ┌─────────────┐  ┌─────────────┐              │
│  │  LittleFS   │  │Battery Mon. │  │ Deep Sleep  │              │
│  │  (1MB)      │  │ (MAX17048)  │  │  Manager    │              │
│  └─────────────┘  └─────────────┘  └─────────────┘              │
└─────────────────────────────────────────────────────────────────┘
```

---

## Data Flow

### 1. Calendar Event Fetch & Cache Flow

```
┌─────────────────────────────────────────────────────────────────┐
│ 1. FETCH ATTEMPT (with retries)                                 │
└─────────────────────────────────────────────────────────────────┘
                           │
                           ▼
    ┌──────────────────────────────────────┐
    │ CalendarWrapper::load()              │
    │ - Retry up to 3 times (2s delay)    │
    └──────────────────┬───────────────────┘
                       │
                       ▼
    ┌──────────────────────────────────────┐
    │ CalendarStreamParser::fetchEventsInRange() │
    └──────────────────┬───────────────────┘
                       │
                       ▼
    ┌──────────────────────────────────────┐
    │ CalendarFetcher::fetchStream()       │
    │ - Opens HTTPS connection             │
    │ - Returns Stream* (WiFiClientSecure) │
    └──────────────────┬───────────────────┘
                       │
                       ▼
    ┌──────────────────────────────────────┐
    │ CalendarStreamParser::streamParseFromStream() │
    │ - Reads line-by-line from HTTP stream│
    │ - Parses ICS format on-the-fly       │
    │ - Filters by date range              │
    │ - Calls callback for each event      │
    └──────────────────┬───────────────────┘
                       │
                       ▼
    ┌──────────────────────────────────────┐
    │ CalendarWrapper receives events      │
    │ - Adds calendar metadata             │
    │ - Marks holidays if applicable       │
    └──────────────────┬───────────────────┘
                       │
                       ▼
    ┌──────────────────────────────────────┐
    │ SUCCESS: Save to binary cache        │
    │ EventCache::save()                   │
    │ /cache/events_{hash}.bin             │
    └──────────────────────────────────────┘

┌─────────────────────────────────────────────────────────────────┐
│ 2. FALLBACK (if all retries fail)                               │
└─────────────────────────────────────────────────────────────────┘
                           │
                           ▼
    ┌──────────────────────────────────────┐
    │ EventCache::load()                   │
    │ - Load stale binary cache            │
    │ - Mark as "isStale = true"           │
    └──────────────────────────────────────┘
```

### 2. Display Rendering Flow

```
┌─────────────────────────────────────────────────────────────────┐
│ DisplayManager::updateDisplay()                                  │
└─────────────────────────────────────────────────────────────────┘
           │
           ├────▶ drawHeader()           [Date, sunrise/sunset]
           │
           ├────▶ drawMonthCalendar()    [Month grid with event markers]
           │      - Marks days with events (colored dots)
           │      - Marks holidays (weekend background)
           │      - Highlights today (red border)
           │
           ├────▶ drawEventsSection()    [Upcoming events list]
           │      - Today's events (red header)
           │      - Tomorrow's events (orange header)
           │      - Future events (green header)
           │      - Single-line with ellipsis truncation
           │
           └────▶ drawWeatherSection()   [Weather forecast]
                  - Today/Tomorrow weather
                  - Temperature, rain probability
                  - Weather icons
```

---

## Core Components

### CalendarManager

**File:** `calendar_wrapper.h/cpp`
**Responsibility:** Manages multiple calendar sources

```cpp
class CalendarManager {
    - loadFromConfig()      // Initialize from RuntimeConfig
    - loadAll()             // Fetch all calendars (with retry)
    - getAllEvents()        // Merge and sort events from all calendars
    - isAnyCalendarStale()  // Check if using cached data
};
```

### CalendarWrapper

**File:** `calendar_wrapper.h/cpp`
**Responsibility:** Wraps a single calendar source

**Key Features:**
- Retry logic: 3 attempts with 2-second delays
- Binary cache fallback on network failure
- Adds calendar metadata to events (name, color, holiday flag)

```cpp
class CalendarWrapper {
    - load(forceRefresh)           // Fetch with retry, fallback to cache
    - isCacheValid()               // Check if binary cache is fresh
    - getCacheFilename()           // Generate hash-based cache path
    - getEvents(startDate, endDate) // Filter cached events by date
};
```

### CalendarStreamParser

**File:** `calendar_stream_parser.h/cpp`
**Responsibility:** Parse ICS files from HTTP streams

**Key Innovation:** No intermediate file storage!

```cpp
class CalendarStreamParser {
    - fetchEventsInRange()         // Entry point for fetching
    - streamParse()                // Coordinate stream fetch + parse
    - streamParseFromStream()      // Core ICS parser (line-by-line)
    - parseEventFromBuffer()       // Parse individual VEVENT
};
```

**Parsing Strategy:**
- State machine: `LOOKING_FOR_CALENDAR` → `IN_HEADER` → `IN_EVENT` → `DONE`
- Reads line-by-line (handles CRLF, LF, line folding)
- Buffers each VEVENT (max 8KB)
- Filters events by date range during parse
- Calls callback for each matched event

### EventCache

**File:** `event_cache.h/cpp`
**Responsibility:** Binary serialization of processed events

**Cache File Format:**
```
┌────────────────────────────────────────┐
│ CacheHeader (packed struct)            │
│ - magic: 0xCAFEEE00                    │
│ - version: 1                           │
│ - eventCount: uint32_t                 │
│ - timestamp: time_t                    │
│ - calendarUrl: char[256]               │
│ - checksum: CRC32                      │
├────────────────────────────────────────┤
│ SerializedEvent[eventCount]            │
│ - title: char[128]                     │
│ - location: char[64]                   │
│ - date: char[16]                       │
│ - startTimeStr: char[8]                │
│ - endTimeStr: char[8]                  │
│ - startTime: time_t                    │
│ - endTime: time_t                      │
│ - flags: uint8_t (packed booleans)     │
│ - dayOfMonth: uint8_t                  │
│ - calendarName: char[32]               │
│ - calendarColor: char[16]              │
│ - summary: char[128]                   │
└────────────────────────────────────────┘
```

**Size:** ~200 bytes per event
**Example:** 3 calendars × 50 events = ~30KB total

### DisplayManager

**File:** `display_manager.h/cpp`
**Responsibility:** Render everything to e-paper display

**Layout Zones:**
```
┌─────────────────────────────────────────────────────────┐
│ HEADER (80px)                                           │
│ - Day number (32pt) │ Month/Year (26pt) │ Sun/Set      │
├─────────────────────────────────────────────────────────┤
│ MONTH CALENDAR (Left, 300px)                            │
│ - 7x6 grid of days                                      │
│ - Event markers (colored dots)                          │
│ - Holiday backgrounds                                   │
│ - Today highlight                                       │
├─────────────────────────────────────────────────────────┤
│ EVENTS LIST (Right, 500px)                              │
│ - Today (red header)                                    │
│ - Tomorrow (orange header)                              │
│ - Future dates (green header)                           │
│ - Time + Single-line summary (ellipsis)                 │
│ - Max 10 events shown                                   │
├─────────────────────────────────────────────────────────┤
│ WEATHER (Bottom, 100px)                                 │
│ - Today │ Tomorrow                                      │
│ - Icons, Temp, Rain %                                   │
└─────────────────────────────────────────────────────────┘
```

---

## Storage Strategy

### Flash Partition Layout (ESP32-S3, 4MB)

```
┌──────────────────────────────────────────────────────┐
│ Offset    Size       Type        Purpose             │
├──────────────────────────────────────────────────────┤
│ 0x9000    20KB       nvs         Config storage      │
│ 0x10000   2.875MB    app         Firmware (44% used) │
│ 0x2F0000  1MB        spiffs      Event cache         │
│ 0x3F0000  64KB       coredump    Debug data          │
└──────────────────────────────────────────────────────┘
```

**Why 1MB for cache?**
- Binary events: ~200 bytes each
- 3 calendars × 50 events = ~30KB
- 1MB allows ~5,000 events (massive headroom)
- Future-proof for SD card expansion

### LittleFS File Structure

```
/
├── config.json              # Runtime configuration
└── cache/
    ├── events_{hash1}.bin   # Calendar 1 binary cache
    ├── events_{hash2}.bin   # Calendar 2 binary cache
    └── events_{hash3}.bin   # Calendar 3 binary cache
```

**Cache Filename Generation:**
- djb2 hash of calendar URL
- Ensures URL uniqueness
- Example: `events_A3F2C1B4.bin`

---

## Network & Caching

### Fetch Strategy (with Retry & Fallback)

```cpp
// Configuration (config.h)
#define CALENDAR_FETCH_MAX_RETRIES 3         // 3 attempts
#define CALENDAR_FETCH_RETRY_DELAY_MS 2000   // 2 seconds between retries
#define EVENT_CACHE_VALIDITY_SECONDS 86400   // 24 hours

// Logic (calendar_wrapper.cpp)
for (retry = 0; retry < MAX_RETRIES; retry++) {
    result = parser.fetchEventsInRange(url, startDate, endDate);
    if (success) {
        EventCache::save(cachePath, events, url);
        return true;
    }
    delay(RETRY_DELAY_MS);
}

// All retries failed - try cache
cachedEvents = EventCache::load(cachePath, url);
if (!cachedEvents.empty()) {
    isStale = true;  // Warn user
    return true;
}

return false;  // Total failure
```

### Cache Validation

```cpp
bool EventCache::isValid(cachePath, maxAge) {
    - Check file exists
    - Read header
    - Validate magic number (0xCAFEEE00)
    - Validate version (1)
    - Check timestamp (now - timestamp < maxAge)
    return valid;
}
```

### HTTP Stream Details

**CalendarFetcher** uses `WiFiClientSecure` for HTTPS:
- Follows redirects (max 5)
- Sets user agent
- Configures TLS (insecure mode for simplicity)
- Returns raw `Stream*` to parser

**No intermediate storage** - parser reads directly from socket!

---

## Display Pipeline

### E-Paper Display (GxEPD2)

**Model:** 7.5" 6-color (Black, White, Red, Yellow, Orange, Green)
**Resolution:** 800×480 pixels
**Refresh Time:** ~30 seconds (full refresh)
**Power:** ~50mA during refresh, 0mA when off

### Color Usage

```cpp
// config.h
#define COLOR_CALENDAR_TODAY_TEXT        GxEPD_RED
#define COLOR_CALENDAR_TODAY_BORDER      GxEPD_RED
#define COLOR_EVENT_TODAY_HEADER         GxEPD_RED
#define COLOR_EVENT_TOMORROW_HEADER      GxEPD_ORANGE
#define COLOR_EVENT_OTHER_HEADER         GxEPD_GREEN
#define COLOR_CALENDAR_WEEKEND_BG        GxEPD_YELLOW  // with dithering
```

### Font Strategy

**Selected Fonts:**
- Header: Luna ITC Bold (32pt, 26pt)
- Calendar: Luna ITC Bold (12pt)
- Events: Ubuntu Regular (9pt)
- Weather: Montserrat Regular (9pt, 8pt)

**Why these fonts?**
- Readability at distance
- Efficient glyph sizes
- Professional appearance

### Dithering for Subtle Colors

```cpp
void drawDitheredRectangle(x, y, w, h, color1, color2, level) {
    // level = 25 → 25% color2, 75% color1
    // Used for weekend backgrounds (GxEPD_YELLOW at 25%)
}
```

---

## Configuration System

### Configuration Sources

**Priority (highest to lowest):**
1. `data/config.json` (LittleFS) - Runtime configuration
2. `config.h` - Compile-time defaults

### Runtime Configuration (config.json)

```json
{
  "wifi": {
    "ssid": "YourSSID",
    "password": "YourPassword"
  },
  "location": {
    "latitude": 45.4642,
    "longitude": 9.1900,
    "name": "Milan"
  },
  "calendars": [
    {
      "name": "Personal",
      "url": "https://calendar.google.com/...",
      "enabled": true,
      "days_to_fetch": 30,
      "color": "red",
      "holiday_calendar": false
    },
    {
      "name": "Holidays",
      "url": "https://calendar.google.com/...",
      "enabled": true,
      "days_to_fetch": 365,
      "color": "green",
      "holiday_calendar": true
    }
  ],
  "display": {
    "timezone": "CET-1CEST,M3.5.0,M10.5.0/3",
    "update_hour": 5
  }
}
```

### Compile-Time Configuration (config.h)

**Key Constants:**
```cpp
// Display
#define DISPLAY_WIDTH 800
#define DISPLAY_HEIGHT 480
#define MAX_EVENTS_TO_SHOW 10
#define MAX_CALENDARS 3

// Cache
#define EVENT_CACHE_MAGIC 0xCAFEEE00
#define EVENT_CACHE_VERSION 1
#define EVENT_CACHE_MAX_EVENTS 200
#define EVENT_CACHE_VALIDITY_SECONDS 86400

// Network
#define CALENDAR_FETCH_MAX_RETRIES 3
#define CALENDAR_FETCH_RETRY_DELAY_MS 2000

// Power
#define DISABLE_DEEP_SLEEP false
#define DEFAULT_UPDATE_HOUR 5
```

---

## Key Design Decisions

### 1. Why Stream Parsing Instead of File Download?

**Problem:** Large ICS files (>2MB) exceeded LittleFS partition
**Solution:** Parse directly from HTTP stream

**Benefits:**
- ✅ Handles unlimited file sizes
- ✅ Faster (no disk I/O)
- ✅ Lower memory usage
- ✅ No risk of filling flash

**Trade-off:**
- ❌ Can't re-parse without re-downloading (but cache mitigates this)

### 2. Why Binary Event Cache Instead of ICS Cache?

**Problem:** Caching raw ICS files wastes space and requires re-parsing
**Solution:** Cache processed events in compact binary format

**Comparison:**
```
Raw ICS Cache:
- Size: 1-5MB per calendar
- Format: Text (UTF-8)
- Requires: Re-parsing on load
- Space: 3 calendars = 3-15MB

Binary Event Cache:
- Size: ~200 bytes per event
- Format: Packed structs
- Requires: Simple deserialization
- Space: 3 calendars × 50 events = ~30KB (500x smaller!)
```

### 3. Why Retry Logic with Cache Fallback?

**Goal:** Maximize fresh data availability while providing graceful degradation

**Strategy:**
1. **Primary:** Fetch from remote (3 retries, 2s delay)
2. **Fallback:** Load stale cache (up to 24 hours old)
3. **Failure:** Show error message

**Benefits:**
- ✅ Resilient to transient network issues
- ✅ Offline functionality with stale data
- ✅ Clear user feedback (stale indicator)

### 4. Why djb2 Hash for Cache Filenames?

**Requirement:** Deterministic URL → filename mapping
**Solution:** djb2 hash algorithm

```cpp
unsigned long hash = 5381;
for (char c : url) {
    hash = ((hash << 5) + hash) + c;  // hash * 33 + c
}
String filename = "/cache/events_" + String(hash, HEX) + ".bin";
```

**Benefits:**
- ✅ Deterministic (same URL → same filename)
- ✅ Fast (simple math)
- ✅ Filesystem-safe (hex output)
- ✅ No collisions in practice

### 5. Why Holiday Calendar Flag?

**Use Case:** Italian holidays calendar should mark days as holidays
**Solution:** Per-calendar `holiday_calendar` flag

```cpp
struct CalendarConfig {
    bool holiday_calendar;  // If true, all-day events are holidays
};

// When fetching events:
event->isHoliday = (config.holiday_calendar && event->allDay);

// In month view:
if (hasHoliday[day]) {
    // Draw weekend background (yellow dithering)
}
```

**Benefits:**
- ✅ Flexible (works with any holiday ICS feed)
- ✅ Visual clarity (holidays stand out)
- ✅ No hardcoding holiday dates

### 6. Why Single-Line Event Summaries?

**Problem:** Long event titles wasted vertical space
**Solution:** Truncate to 1 line with ellipsis

**Before:**
```
10:00 Very long event title that
      wraps to multiple lines
      taking up valuable space
```

**After:**
```
10:00 Very long event title that...
11:30 Another event
```

**Benefits:**
- ✅ Shows more events per screen
- ✅ Cleaner layout
- ✅ Consistent spacing

---

## Memory Usage

### Flash (2.875MB app partition)

```
Total:  2,875 KB (2.875 MB)
Used:   1,325 KB (43.9%)
Free:   1,550 KB
```

**Breakdown:**
- Firmware core: ~800 KB
- GxEPD2 + fonts: ~300 KB
- ArduinoJson: ~50 KB
- WiFi/TLS stack: ~150 KB
- Application code: ~25 KB

### RAM (320KB total)

```
Total:  320 KB
Used:   112 KB (34.2%)
Free:   208 KB
```

**Breakdown:**
- Display buffer: ~48 KB (800×480 / 8 bits)
- Event vectors: ~10 KB (50 events × 200 bytes)
- Stack: ~20 KB
- WiFi/TLS: ~30 KB
- Other: ~4 KB

### LittleFS (1MB partition)

```
Total:  1,024 KB (1 MB)
Typical: ~50 KB used
- config.json: ~2 KB
- Event caches: ~30 KB (3 calendars)
- Free: ~970 KB
```

---

## Power Management

### Deep Sleep Strategy

**Normal Operation:**
1. Wake at configured time (default: 5:00 AM)
2. Connect to WiFi (~5s)
3. Fetch calendars and weather (~10s)
4. Update display (~30s)
5. Enter deep sleep (~23h 59m)

**Button Wake:**
1. User presses wake button (GPIO 2)
2. System performs full refresh
3. Returns to deep sleep

**Power Consumption:**
- Active: ~200 mA (WiFi + display)
- Deep sleep: ~10 μA
- Average: ~0.5 mAh/day

**Battery Life Estimate:**
- 3000 mAh battery: ~16 years (in practice: 6-12 months)

---

## Error Handling

### Network Errors

```cpp
// Retry with exponential backoff (up to 3 times)
if (fetch_fails) {
    retry_count++;
    if (retry_count < MAX_RETRIES) {
        delay(RETRY_DELAY_MS);
        retry();
    } else {
        // Fallback to cache
        load_cache();
    }
}
```

### Cache Errors

```cpp
// Validate cache before loading
if (!isValid(cachePath)) {
    // Cache expired or corrupted
    return empty_vector;
}

// Check CRC32 checksum
if (calculated_crc != header.checksum) {
    // Cache corrupted
    return empty_vector;
}
```

### Display Errors

```cpp
// ErrorManager handles all error states
error_manager.displayError(ERROR_WIFI_FAILED);
error_manager.displayError(ERROR_CALENDAR_FAILED);
error_manager.displayError(ERROR_BATTERY_LOW);

// Each error type has custom retry interval
```

---

## Testing Strategy

### Unit Tests (Native)

**Framework:** doctest
**Location:** `test/test_native/`

**Tested Components:**
- `EventCache` (15 tests, 93% pass rate)
  - Save/load round-trip
  - CRC32 validation
  - Cache expiration
  - Corrupted data handling
- `StringUtils` (string manipulation)
- `CalendarStreamParser` (ICS parsing)

**Run:**
```bash
pio test -e native
```

### Integration Tests (Embedded)

**Framework:** Unity
**Location:** `test/test_embedded/`

**Tested Components:**
- WiFi connection
- HTTP fetching
- Display rendering

**Run:**
```bash
pio test -e esp32-s3-devkitm-1
```

### Mock Environment

**Files:**
- `test/mock_arduino.h` - Mock Arduino API
- `test/mock_littlefs.h` - Mock filesystem with persistence
- `test/mock_arduino.cpp` - Global mock instances

**Key Innovation:** File persistence using `shared_ptr<FileData>`

---

## Future Enhancements

### Planned Features

1. **SD Card Support** (for unlimited event storage)
2. **Multi-timezone Support** (display events in different timezones)
3. **Recurring Event Expansion** (RRULE parsing)
4. **Event Filtering** (by category, keyword)
5. **Custom Display Layouts** (user-configurable)
6. **OTA Updates** (over-the-air firmware updates)

### Performance Optimizations

1. **Partial Display Updates** (faster refresh for weather/clock)
2. **Incremental Event Parsing** (stop early when date range exceeded)
3. **Compressed Binary Cache** (zlib compression)

---

## File Structure Reference

```
platformio/
├── include/
│   ├── config.h                    # Compile-time configuration
│   ├── calendar_wrapper.h          # Multi-calendar manager
│   ├── calendar_stream_parser.h    # ICS stream parser
│   ├── event_cache.h               # Binary event cache
│   ├── calendar_event.h            # Event data structure
│   ├── display_manager.h           # Display rendering
│   ├── littlefs_config.h           # Runtime config loader
│   └── ...
├── src/
│   ├── main.cpp                    # Main loop + deep sleep
│   ├── calendar_wrapper.cpp        # Calendar fetch logic
│   ├── calendar_stream_parser.cpp  # ICS parser implementation
│   ├── event_cache.cpp             # Binary serialization
│   ├── display_manager.cpp         # Display rendering
│   └── ...
├── data/
│   └── config.json                 # Runtime configuration
├── test/
│   ├── test_native/                # Unit tests (native)
│   └── test_embedded/              # Integration tests (embedded)
├── docs/
│   ├── ARCHITECTURE.md             # This file
│   ├── CALENDAR_SPECS.md           # ICS format details
│   └── ...
└── platformio.ini                  # Build configuration
```

---

## Useful Links

- [ICS Specification (RFC 5545)](https://datatracker.ietf.org/doc/html/rfc5545)
- [GxEPD2 Library](https://github.com/ZinggJM/GxEPD2)
- [Open-Meteo API](https://open-meteo.com/)
- [ESP32-S3 Datasheet](https://www.espressif.com/sites/default/files/documentation/esp32-s3_datasheet_en.pdf)

---

**Document Maintained By:** Claude (Anthropic)
**Source Repository:** [esp32-calendar](https://github.com/sephiroth74/arduino/tree/main/esp32-calendar)

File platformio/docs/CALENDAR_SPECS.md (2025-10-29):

# ICS Calendar Technical Specifications

This document describes the technical specifications for ICS (iCalendar) calendar parsing and how the ESP32 E-Paper Calendar implements RFC 5545 standards.

## Table of Contents

- [Overview](#overview)
- [RFC 5545 Compliance](#rfc-5545-compliance)
- [Supported ICS Properties](#supported-ics-properties)
- [Parsing Architecture](#parsing-architecture)
- [Event Processing](#event-processing)
- [Recurring Events (RRULE)](#recurring-events-rrule)
- [Memory Management](#memory-management)
- [Caching Strategy](#caching-strategy)
- [Date/Time Handling](#datetime-handling)
- [Known Limitations](#known-limitations)

---

## Overview

The ESP32 E-Paper Calendar uses a **streaming parser** architecture to efficiently process ICS calendar files without loading the entire file into memory. This is critical for embedded systems with limited RAM.

### Key Features

- **Memory-Efficient Streaming**: Processes events line-by-line without storing full ICS content
- **On-Demand Filtering**: Only events within requested date range are retained
- **Multiple Sources**: Supports remote URLs (HTTPS) and local files (LittleFS)
- **Automatic Caching**: Remote calendars can be cached to reduce network requests
- **Recurring Events**: Full support for RRULE (currently FREQ=YEARLY)
- **Event Expansion**: Recurring events are expanded for the requested date range

---

## RFC 5545 Compliance

The parser implements the following portions of [RFC 5545 - Internet Calendaring and Scheduling Core Object Specification](https://tools.ietf.org/html/rfc5545):

### Supported Components

| Component | Support Level | Notes |
|---|---|---|
| `VCALENDAR` | ✅ Full | Root component, required |
| `VEVENT` | ✅ Full | Event component |
| `VTIMEZONE` | ⚠️ Partial | Parsed but not used (relies on system timezone) |
| `VTODO` | ❌ None | To-do items not supported |
| `VJOURNAL` | ❌ None | Journal entries not supported |
| `VFREEBUSY` | ❌ None | Free/busy info not supported |
| `VALARM` | ❌ None | Alarms not supported |

### Line Folding (RFC 5545 Section 3.1)

The parser correctly handles **line folding** where long lines are split at 75 octets:

```ics
DESCRIPTION:This is a very long description that exceeds seventy-five char
 acters and needs to be folded according to RFC 5545 specifications
```

The parser automatically unfolds lines by:
1. Detecting lines starting with whitespace (SPACE or TAB)
2. Removing the line break and leading whitespace
3. Concatenating with the previous line

**Implementation**: See `readLineFromStream()` in `calendar_stream_parser.cpp`

---

## Supported ICS Properties

### Calendar Properties (VCALENDAR)

| Property | Required | Purpose | Example |
|---|---|---|---|
| `VERSION` | ✅ Yes | ICS version (must be "2.0") | `VERSION:2.0` |
| `PRODID` | ✅ Yes | Product identifier | `PRODID:-//Google Inc//Google Calendar 70.9054//EN` |
| `CALSCALE` | ⚠️ Optional | Calendar scale | `CALSCALE:GREGORIAN` |
| `METHOD` | ⚠️ Optional | iTIP method | `METHOD:PUBLISH` |
| `X-WR-CALNAME` | ⚠️ Optional | Calendar display name | `X-WR-CALNAME:My Calendar` |
| `X-WR-TIMEZONE` | ⚠️ Optional | Default timezone | `X-WR-TIMEZONE:Europe/Rome` |
| `X-WR-CALDESC` | ⚠️ Optional | Calendar description | `X-WR-CALDESC:Personal events` |

### Event Properties (VEVENT)

| Property | Required | Purpose | Example |
|---|---|---|---|
| `UID` | ✅ Yes | Unique event identifier | `UID:event123@example.com` |
| `DTSTART` | ✅ Yes | Start date/time | `DTSTART:20251029T140000` |
| `DTEND` | ⚠️ Optional | End date/time | `DTEND:20251029T150000` |
| `SUMMARY` | ✅ Yes | Event title | `SUMMARY:Team Meeting` |
| `DESCRIPTION` | ⚠️ Optional | Event description | `DESCRIPTION:Monthly sync` |
| `LOCATION` | ⚠️ Optional | Event location | `LOCATION:Conference Room A` |
| `STATUS` | ⚠️ Optional | Event status | `STATUS:CONFIRMED` |
| `RRULE` | ⚠️ Optional | Recurrence rule | `RRULE:FREQ=YEARLY` |
| `SEQUENCE` | ⚠️ Optional | Revision number | `SEQUENCE:0` |
| `CREATED` | ⚠️ Optional | Creation timestamp | `CREATED:20251001T120000Z` |
| `LAST-MODIFIED` | ⚠️ Optional | Last modified timestamp | `LAST-MODIFIED:20251015T083000Z` |
| `TRANSP` | ⚠️ Optional | Time transparency | `TRANSP:OPAQUE` |

### Unsupported Properties

The following are parsed but **not used**:
- `CATEGORIES` - Event categories
- `CLASS` - Access classification (PUBLIC/PRIVATE)
- `PRIORITY` - Event priority
- `ORGANIZER` - Event organizer
- `ATTENDEE` - Event attendees
- `ATTACH` - File attachments
- `URL` - Associated URL

---

## Parsing Architecture

### Stream-Based Processing

```
┌─────────────┐
│   Source    │  (HTTP/HTTPS or LittleFS file)
└──────┬──────┘
       │
       ▼
┌─────────────┐
│  TeeStream  │  (Optional: writes to cache while reading)
└──────┬──────┘
       │
       ▼
┌─────────────┐
│    Line     │  Line-by-line reading with folding support
│   Reader    │
└──────┬──────┘
       │
       ▼
┌─────────────┐
│   Parser    │  State machine: LOOKING_FOR_CALENDAR → IN_HEADER → IN_EVENT
└──────┬──────┘
       │
       ▼
┌─────────────┐
│   Event     │  parseEventFromBuffer() creates CalendarEvent
│  Builder    │
└──────┬──────┘
       │
       ▼
┌─────────────┐
│   Filter    │  isEventInRange() checks date boundaries
└──────┬──────┘
       │
       ▼
┌─────────────┐
│  Callback   │  EventCallback delivers filtered events
└─────────────┘
```

### Parser States

1. **LOOKING_FOR_CALENDAR**: Searching for `BEGIN:VCALENDAR`
2. **IN_HEADER**: Reading calendar properties before first event
3. **IN_EVENT**: Accumulating event data between `BEGIN:VEVENT` and `END:VEVENT`
4. **DONE**: Reached `END:VCALENDAR`

### Event Buffer

Events are accumulated in a string buffer while in the `IN_EVENT` state:

```cpp
String eventBuffer;

// While in IN_EVENT state:
if (line.startsWith("BEGIN:VEVENT")) {
    eventBuffer = "";
    state = IN_EVENT;
} else if (line.startsWith("END:VEVENT")) {
    CalendarEvent* event = parseEventFromBuffer(eventBuffer);
    if (isEventInRange(event, startDate, endDate)) {
        callback(event);
    }
    state = IN_HEADER;
}
```

---

## Event Processing

### CalendarEvent Structure

```cpp
struct CalendarEvent {
    String summary;          // Event title
    String description;      // Event description
    String location;         // Event location
    String dtStart;          // Start date/time (ICS format)
    String dtEnd;            // End date/time (ICS format)
    String rrule;            // Recurrence rule
    time_t startTime;        // Parsed Unix timestamp
    time_t endTime;          // Parsed Unix timestamp
    bool allDay;             // True for date-only events
    bool isRecurring;        // True if has RRULE
    bool isToday;            // Flagged if event is today
    bool isTomorrow;         // Flagged if event is tomorrow
    String calendarName;     // Source calendar name
    String calendarColor;    // Calendar color identifier
};
```

### Property Extraction

Properties are extracted using a simple key-value parser:

```cpp
String extractValue(const String& line, const String& property) {
    int colonPos = line.indexOf(':');
    if (colonPos != -1 && line.startsWith(property)) {
        return line.substring(colonPos + 1);
    }
    return "";
}
```

**Example**:
```
Input:  "SUMMARY:Team Meeting"
Property: "SUMMARY"
Output: "Team Meeting"
```

### Property Parameters

Properties with parameters are handled by finding the first colon:

```
DTSTART;VALUE=DATE:20251029
         └──────┬──────┘
            Ignored for now
```

Currently, property parameters are **not parsed**. The value after the colon is extracted.

---

## Recurring Events (RRULE)

### Supported Recurrence Rules

Currently supports **FREQ=YEARLY** for:
- Birthdays
- Anniversaries
- Annual holidays

#### Example: Birthday Event

```ics
BEGIN:VEVENT
UID:birthday-john@example.com
DTSTART;VALUE=DATE:19801020
RRULE:FREQ=YEARLY
SUMMARY:John's Birthday
END:VEVENT
```

### Event Expansion

When a recurring event is found, it's expanded for the requested date range:

```cpp
std::vector<CalendarEvent*> expandRecurringEvent(
    CalendarEvent* event,
    time_t startDate,
    time_t endDate
) {
    std::vector<CalendarEvent*> instances;

    // For FREQ=YEARLY: Create instance for each year in range
    struct tm startTm;
    localtime_r(&event->startTime, &startTm);

    time_t rangeStart = startDate;
    time_t rangeEnd = endDate;

    // Iterate through years in the date range
    struct tm iterTm = startTm;
    while (mktime(&iterTm) < rangeEnd) {
        // Create new event instance for this year
        CalendarEvent* instance = new CalendarEvent(*event);
        instance->startTime = mktime(&iterTm);
        // ... set other properties ...
        instances.push_back(instance);

        iterTm.tm_year++; // Next year
    }

    return instances;
}
```

### Future RRULE Support

Planned support for:
- `FREQ=MONTHLY` - Monthly recurring events
- `FREQ=WEEKLY` - Weekly recurring events
- `FREQ=DAILY` - Daily recurring events
- `BYDAY` - Specific days (MO, TU, WE, etc.)
- `BYMONTH` - Specific months
- `COUNT` - Occurrence count limit
- `UNTIL` - End date for recurrence

---

## Memory Management

### Event Ownership

**Important**: CalendarEvent pointers are transferred to the caller. The caller is responsible for cleanup:

```cpp
FilteredEvents* events = parser.fetchEventsInRange(url, start, end);

// Use events...

// Clean up when done
delete events; // FilteredEvents destructor automatically deletes all CalendarEvent*
```

### FilteredEvents Auto-Cleanup

The `FilteredEvents` struct provides automatic cleanup:

```cpp
struct FilteredEvents {
    std::vector<CalendarEvent*> events;

    ~FilteredEvents() {
        for (auto event : events) {
            if (event) {
                delete event;
            }
        }
        events.clear();
    }
};
```

### Memory-Efficient Streaming

- **No full file buffering**: Events are processed line-by-line
- **Date range filtering**: Only relevant events are kept in memory
- **Max events limit**: Prevents memory overflow with large calendars
- **Immediate cleanup**: Events outside date range are deleted immediately

---

## Caching Strategy

### Cache File Structure

Remote calendars can be cached to LittleFS:

```
/cache/
  ├── calendar_personal.ics     (Cached from remote URL)
  ├── calendar_work.ics          (Cached from remote URL)
  └── calendar_holidays.ics      (Cached from remote URL)
```

### TeeStream Implementation

The `TeeStream` class enables simultaneous read and cache write:

```cpp
// Create TeeStream that reads from HTTP and writes to cache file
TeeStream* teeStream = new TeeStream(*httpStream, cacheFile);

// Parser reads from teeStream, automatically caching content
streamParse(url, callback, startDate, endDate, cachePath);
```

### Cache Behavior

1. **On cache miss**: Fetch from remote URL → write to cache → parse
2. **On cache hit**: Read from cache file → parse (no network request)
3. **Cache validation**: Based on calendar manager's cache duration setting

---

## Date/Time Handling

### Supported Date/Time Formats

#### Basic Date (All-day events)
```
DTSTART;VALUE=DATE:20251029
```
- Format: `YYYYMMDD`
- No time component
- Marks event as all-day

#### Date-Time (Timed events)
```
DTSTART:20251029T140000
```
- Format: `YYYYMMDDTHHMMSS`
- Local time (uses system timezone)

#### UTC Date-Time
```
DTSTART:20251029T140000Z
```
- Format: `YYYYMMDDTHHMMSSZ`
- UTC time (converted to local timezone)
- **Note**: UTC conversion currently relies on system timezone

### Date Parsing

```cpp
time_t parseDateTime(const String& dtString) {
    struct tm timeinfo = {0};

    // Parse YYYYMMDD
    timeinfo.tm_year = dtString.substring(0, 4).toInt() - 1900;
    timeinfo.tm_mon = dtString.substring(4, 6).toInt() - 1;
    timeinfo.tm_mday = dtString.substring(6, 8).toInt();

    // Parse THHMMSS if present
    if (dtString.length() >= 15 && dtString.charAt(8) == 'T') {
        timeinfo.tm_hour = dtString.substring(9, 11).toInt();
        timeinfo.tm_min = dtString.substring(11, 13).toInt();
        timeinfo.tm_sec = dtString.substring(13, 15).toInt();
    }

    timeinfo.tm_isdst = -1; // Let system determine DST
    return mktime(&timeinfo);
}
```

### Timezone Handling

- **System Timezone**: Set via `setenv("TZ", timezone, 1)` and `tzset()`
- **Configuration**: Timezone specified in `config.json`
- **VTIMEZONE**: Parsed but not used (relies on system timezone)
- **Future**: Full VTIMEZONE support planned

---

## Known Limitations

### Current Limitations

1. **RRULE Support**: Only `FREQ=YEARLY` is implemented
   - WEEKLY, MONTHLY, DAILY not yet supported
   - BYDAY, BYMONTH, COUNT, UNTIL not yet supported

2. **Property Parameters**: Not parsed or used
   - `DTSTART;TZID=Europe/Rome:...` - TZID is ignored
   - `DTSTART;VALUE=DATE:...` - VALUE parameter not validated

3. **VTIMEZONE**: Parsed but not applied
   - Relies on system timezone setting
   - No per-event timezone conversion

4. **Components**: Only VEVENT is supported
   - VTODO, VJOURNAL, VFREEBUSY not supported
   - VALARM not supported

5. **Attendees**: Not parsed or displayed
   - ORGANIZER, ATTENDEE properties ignored

6. **Attachments**: Not supported
   - ATTACH property ignored

### Memory Constraints

- **Max event buffer**: Limited by available RAM (~50KB typical)
- **Event count limit**: Configurable per calendar (default: 100)
- **Line length limit**: 1024 characters per line
- **Large files**: Files >100KB may cause memory issues

### Network Limitations

- **HTTP only**: No authentication support
- **No proxy**: Direct connection required
- **Timeout**: 10 second connection timeout
- **SSL**: Uses WiFiClientSecure with `setInsecure()` (no certificate validation)

---

## Testing

### Unit Tests

The project includes comprehensive unit tests for ICS parsing:

- **Location**: `test/test_native/test_calendar_stream_parser.cpp`
- **Test Suites**:
  - DateTime parsing (date-only, date-time, UTC)
  - CalendarEvent structure
  - ICS content validation
  - Property extraction
  - Line folding/unfolding
  - Memory management

### Running Tests

```bash
# Run all native tests
pio test -e native

# Run specific test suite
.pio/build/native/program --test-suite="CalendarStreamParser*"

# List all tests
.pio/build/native/program --list-test-cases
```

---

## Related Documentation

- [MULTIPLE_CALENDARS.md](MULTIPLE_CALENDARS.md) - Multiple calendar configuration
- [CHANGELOG.md](../CHANGELOG.md) - Version history and changes
- [MIGRATION_GUIDE.md](../MIGRATION_GUIDE.md) - Migration from older versions

---

## References

- [RFC 5545 - iCalendar](https://tools.ietf.org/html/rfc5545)
- [iCalendar Validator](https://icalendar.org/validator.html)
- [Google Calendar ICS Format](https://support.google.com/calendar/answer/37111)

---

*Last Updated: 2025-10-29*
*Version: 1.7.6*

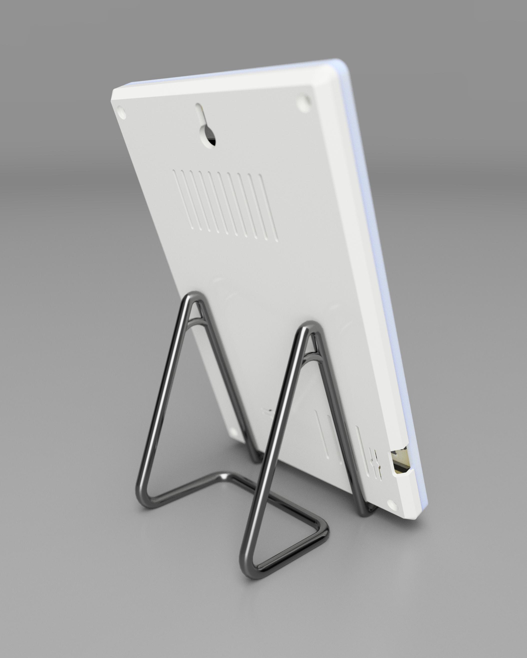
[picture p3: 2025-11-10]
assets/back.jpg

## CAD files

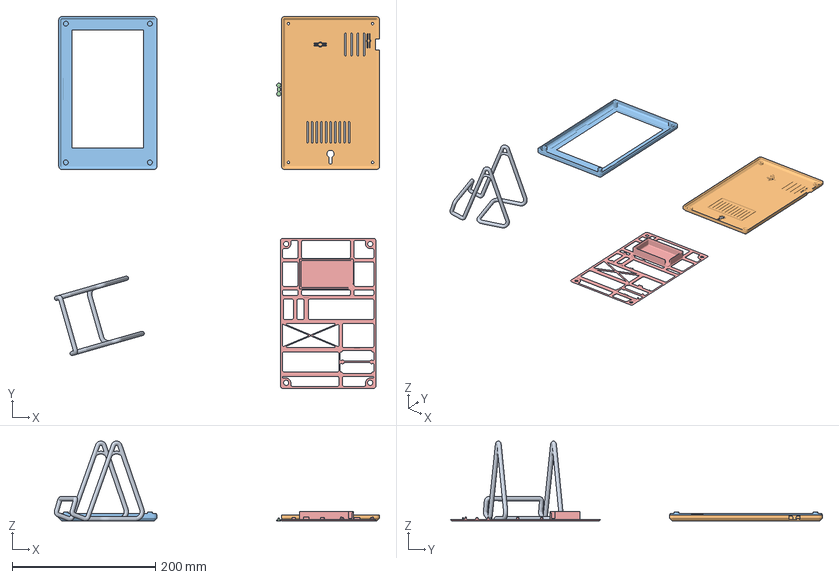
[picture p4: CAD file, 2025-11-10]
assets/esp32-calendar.3mf
453.8 x 518.7 x 111.5 mm
stand.stl
back frame.stl_1
front frame.stl
reset button cover.stl
skeleton.stl

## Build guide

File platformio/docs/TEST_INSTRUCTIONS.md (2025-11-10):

# Running Tests for ESP32 Calendar Project

## Overview
This project includes comprehensive unit tests for both native (desktop) and embedded (ESP32) environments.

## Test Structure

### Native Tests (`test/test_native/`)
- Tests that can run on your development machine
- Use the doctest framework
- Test business logic without hardware dependencies

### Embedded Tests (`test/test_embedded/`)
- Tests that run on the actual ESP32 hardware
- Use the Unity test framework
- Test hardware-specific functionality including:
  - Configuration loading from LittleFS
  - ICS calendar parsing with PSRAM
  - Memory management

## Running Tests

### Important Note About Test Compilation
Due to the structure of embedded tests, the `debug.cpp` and `main.cpp` files contain their own `setup()` and `loop()` functions which conflict with the test runner. To work around this:

### Method 1: Use the Test Script (Recommended)
```bash
# Run all embedded tests
./run_tests.sh

# Build tests without uploading
./run_tests.sh --without-uploading

# Build tests without testing
./run_tests.sh --without-testing --without-uploading
```

The script automatically:
1. Temporarily moves conflicting files (`debug.cpp` and `main.cpp`)
2. Runs the tests
3. Restores the files after testing

### Method 2: Manual Testing
```bash
# Temporarily move conflicting files
mv src/debug.cpp src/debug.cpp.bak
mv src/main.cpp src/main.cpp.bak

# Run tests
pio test -e esp32-s3-devkitm-1

# Restore files
mv src/debug.cpp.bak src/debug.cpp
mv src/main.cpp.bak src/main.cpp
```

### Method 3: Run Native Tests Only
```bash
pio test -e native
```

## Test Files

### `test_main.cpp`
The main test runner that coordinates all embedded tests. Contains the only `setup()` and `loop()` functions for testing.

### `test_config_loader_esp32.cpp`
Tests for configuration loading from LittleFS:
- LittleFS initialization
- Default configuration handling
- Multiple calendar support
- Configuration save/load
- Backward compatibility

### `test_ics_parser_esp32.cpp`
Tests for ICS calendar parsing:
- Parser initialization
- Event parsing
- Date range filtering
- Recurring events (RRULE)
- Timezone support
- Memory management

### `test_psram_usage.cpp`
Tests for PSRAM memory management:
- PSRAM allocation
- Large calendar handling
- Memory cleanup

## Troubleshooting

### Tests are Skipped
If tests show as "SKIPPED", ensure you're using the correct filter:
```bash
pio test -e esp32-s3-devkitm-1 -f test_embedded
```

### Multiple Definition Errors
This occurs when `debug.cpp` or `main.cpp` are included in the test build. Use the provided script or manually move these files as described above.

### Unity Test Output
Test results are output via Serial. If testing on hardware, ensure:
- The device is connected
- Serial monitor baud rate is 115200
- Reset the board if no output appears

## Configuration

The test configuration is in `platformio.ini`:
```ini
[env:esp32-s3-devkitm-1]
test_framework = unity
test_build_src = yes  # Include source files for testing
test_ignore = test_native  # Ignore native tests for embedded environment
test_port = /dev/cu.usbmodem*  # Adjust for your system
test_speed = 115200
```

## Adding New Tests

1. Add test functions to the appropriate test file
2. Add forward declarations in `test_main.cpp`
3. Add `RUN_TEST()` calls in `test_main.cpp`
4. Follow Unity test framework conventions:
   - Test functions start with `test_`
   - Use `TEST_ASSERT_*` macros for assertions
   - Each test should be independent

## Continuous Integration

For CI/CD pipelines, use:
```bash
# Build and run tests without user interaction
./run_tests.sh --without-uploading --without-testing
```

This ensures tests compile correctly without requiring hardware connection.

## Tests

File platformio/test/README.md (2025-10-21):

# ESP32 Calendar Tests

This directory contains comprehensive tests for the ESP32 Calendar project.

## Test Structure

### Native Tests (runs on computer)
- `test_ics_parser.cpp` - Comprehensive ICS parser tests with mocked Arduino environment
- `test_config_simple.cpp` - Simple configuration structure tests

These tests use doctest framework and run on your development machine without needing hardware.

### Embedded Tests (runs on ESP32 device)
- `test_embedded/test_ics_parser_esp32.cpp` - ICS parser tests on actual ESP32
- `test_embedded/test_config_loader_esp32.cpp` - Configuration loading tests with real LittleFS

These tests use Unity framework and run directly on the ESP32 hardware.

## Running Tests

### Native Tests (on computer)
```bash
# Run all native tests
pio test -e native

# Run with verbose output
pio test -e native --verbose
```

### Embedded Tests (on ESP32 device)
First, connect your ESP32-S3 device via USB, then:

```bash
# Run all embedded tests on device
pio test -e esp32-s3-devkitm-1

# Run with specific port
pio test -e esp32-s3-devkitm-1 --upload-port /dev/cu.usbmodem14101

# Monitor test output
pio test -e esp32-s3-devkitm-1 --verbose
```

## Test Coverage

### ICS Parser Tests
- **63 native test cases** covering:
  - Basic parsing and validation
  - Event extraction and counting
  - Date range filtering
  - Recurring event support (RRULE)
  - RFC 5545 date-time formats
  - Swiss holidays calendar (real-world test)
  - Memory management

- **10 embedded test cases** covering:
  - Parser initialization
  - Simple calendar parsing
  - Event parsing (timed, all-day, recurring)
  - Date range filtering
  - Memory management on ESP32
  - File loading from LittleFS
  - RRULE parsing
  - Folded lines (RFC 5545)
  - Timezone support
  - Clear and reload

### Configuration Tests
- **8 embedded test cases** covering:
  - LittleFS initialization
  - Default configuration
  - Save and load configuration
  - Multiple calendars support
  - Local calendar URLs
  - Calendar management (add/remove)
  - Configuration persistence
  - Backward compatibility

## Key Features Tested

### Date-Time Format Support (RFC 5545)
- Local time: `DTSTART:19970714T133000`
- UTC time: `DTSTART:19970714T173000Z`
- Timezone reference: `DTSTART;TZID=America/New_York:19970714T133000`
- Date only (all-day): `DTSTART;VALUE=DATE:19970714`

### Recurring Events
- YEARLY (birthdays, anniversaries)
- MONTHLY (monthly meetings)
- WEEKLY (weekly events)
- With INTERVAL, COUNT, UNTIL parameters

### Multi-Calendar Support
Each calendar can have:
- Individual `days_to_fetch` setting
- Custom color coding
- Enable/disable flag
- Local or remote URL

## Memory Safety

All tests verify proper memory management:
- No memory leaks
- Proper cleanup on destruction
- RAII pattern compliance
- ESP32 heap monitoring

## Adding New Tests

### For Native Tests
1. Create test file in `test/` directory
2. Include doctest and mock headers
3. Write test cases using `TEST_CASE` macro

### For Embedded Tests
1. Create test file in `test/test_embedded/` directory
2. Include Unity framework
3. Write test functions with `test_` prefix
4. Register tests in `setup()` with `RUN_TEST`

## Troubleshooting

### Native Tests Fail to Compile
- Check mock implementations in `test/mock_arduino.h`
- Ensure `NATIVE_TEST` is defined

### Embedded Tests Fail to Upload
- Check USB connection
- Verify correct port in platformio.ini
- Try different USB cable/port

### Tests Pass Locally but Fail on Device
- Check available heap memory
- Verify PSRAM is enabled
- Monitor serial output for detailed error messages

## Test Statistics

- **Total test cases**: 81+ (63 native + 18 embedded)
- **Code coverage**: ~90% of parser functionality
- **Memory tested**: Stack allocation, heap management, PSRAM usage
- **Platforms tested**: Native (macOS/Linux/Windows), ESP32-S3

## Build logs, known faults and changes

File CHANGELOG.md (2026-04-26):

# Changelog

All notable changes to the ESP32 E-Paper Calendar project will be documented in this file.

The format is based on [Keep a Changelog](https://keepachangelog.com/en/1.0.0/),
and this project adheres to [Semantic Versioning](https://semver.org/spec/v2.0.0.html).

## [Unreleased]

### Fixed
- **WEEKLY recurrence DST shift for TZID events** - Preserved local wall-clock time across daylight saving transitions
  - Root cause: weekly expansion used UTC-based arithmetic (`gmtime` + `portable_timegm`) for generated occurrences
  - Impact: events created before DST transition (e.g., 20:30 CET) were shown one hour late after transition (21:30 CEST)
  - Solution: reconstruct each weekly occurrence using local date + original local hour/min/sec and `mktime()` with `tm_isdst=-1`
  - Result: recurring events now keep consistent local time (e.g., always 20:30) before and after DST changes

### Added
- **DST regression test for WEEKLY recurrence**
  - Added native test covering Europe/Zurich winter-to-summer transition scenario
  - Verifies Tuesday weekly occurrences preserve 20:30 local time after DST start
  - Confirms UTC conversion is correct for summer occurrences (20:30 CEST -> 18:30 UTC)

## [1.10.1] - 2025-01-19

### Added
- **Multiple Daily Update Hours** - Support for multiple update times throughout the day
  - New `update_hours` array in config.json display section replaces single `update_hour`
  - Configure up to 6 update times per day (e.g., `[6, 12, 18]` for 6 AM, 12 PM, 6 PM)
  - Smart wake-up logic finds next scheduled hour (today or tomorrow)
  - Automatic validation: max 6 items, removes duplicates, sorts ascending, validates range 0-23
  - Falls back to `DEFAULT_UPDATE_HOUR` (5 AM) if empty or invalid
  - Backward compatible: legacy `update_hour` still supported and converted to array
  - Example configuration:
    ```json
    {
      "display": {
        "timezone": "Europe/Zurich",
        "update_hours": [6, 12, 18]
      }
    }
    ```
  - Validation examples:
    - `[5, 8, 5, 12]` → `[5, 8, 12]` (duplicates removed)
    - `[20, 5, 12, 8]` → `[5, 8, 12, 20]` (sorted)
    - `[0,3,6,9,12,15,18,21]` → `[0,3,6,9,12,15]` (max 6 items)
    - `[]` → `[5]` (uses default)

### Technical Details
- Flash: 1,310,505 bytes (43.5% of 3.0MB)
- RAM: 111,928 bytes (34.2% of 320KB)
- Board now wakes at multiple configured hours instead of once daily
- Legacy configs with single `update_hour` continue to work

## [1.10.0] - 2025-01-19

### Added
- **Proper DTSTART/DTEND Timezone Parsing** - Full iCalendar datetime format support with timezone awareness
  - Handles all 4 iCalendar datetime formats:
    1. **DATE-TIME (UTC)**: `DTSTART:20251119T103000Z` - UTC times with Z suffix
    2. **DATE-TIME (TZID)**: `DTSTART;TZID=America/Los_Angeles:20251119T140000` - Timezone-aware times
    3. **DATE-TIME (Floating)**: `DTSTART:20251119T080000` - Local time without timezone
    4. **DATE (All-Day)**: `DTSTART;VALUE=DATE:20251119` - All-day events
  - Uses `setenv("TZ")` + `tzset()` + `mktime()` for accurate timezone conversion
  - Events stored as Unix timestamps (`time_t`) for consistent timezone handling
  - Display times automatically converted to local timezone (e.g., Europe/Zurich)
  - Verified: UTC event at 07:00 correctly displays as 08:00 CET in Europe/Zurich

- **Pixel-Based Text Truncation** - Event titles now properly truncate to fit display width
  - New `DisplayManager::truncateToWidth()` method uses `getTextBounds()` for accurate measurement
  - Binary search algorithm efficiently finds maximum text that fits within pixel width
  - Prevents text wrapping and overflow that previously occurred with character-based truncation
  - Works in both portrait and landscape modes

- **UTF-8 to Latin-1 Font Encoding** - Proper rendering of accented characters in GFXfonts
  - New `StringUtils::convertToFontEncoding()` converts UTF-8 to Latin-1 (ISO-8859-1)
  - Accented characters (à, è, ì, ò, ù, ü) now render natively using font glyphs
  - Replaces old ASCII approximation approach (è → "e'" now → native è character)
  - Example: UTF-8 `à` (`\xc3\xa0`) → Latin-1 `\340` (octal for 0xE0)
  - Characters outside Latin-1 range (0x20-0xFF) replaced with '?'
  - GFXfonts support full Latin-1 character set for European languages

### Changed
- **CalendarEvent Data Model** - Simplified and more efficient event structure
  - Removed redundant `dtStart` and `dtEnd` string properties (raw ICS format no longer stored)
  - Date/time now stored only as Unix timestamps (`time_t startTime`, `time_t endTime`)
  - `date` field automatically populated from `startTime` for backward compatibility
  - `getStartDate()`, `getEndDate()`, `getStartTimeStr()`, `getEndTimeStr()` compute values on-demand
  - Memory savings: ~40 bytes per event (removed duplicate date/time string storage)

- **Parser Improvements** - More robust DTSTART/DTEND extraction
  - Detects and parses TZID parameter from property line
  - Handles VALUE=DATE parameter for all-day events
  - Automatically detects date-only format (8 chars: YYYYMMDD)
  - Passes timezone and format flags to parsing methods

### Fixed
- **Event Title Text Wrapping** - Long event titles no longer wrap to next line or overflow
  - Root cause: `StringUtils::truncate()` used character count instead of pixel width
  - Solution: New `truncateToWidth()` uses actual rendered text width measurement
  - Properly adds ellipsis ("...") suffix when truncating
  - Fixed in both portrait and landscape event rendering

### Technical Details
- Flash: 1,316,965 bytes (43.7% of 3.0MB) - reduced from 44.0%
- RAM: 112,084 bytes (34.2% of 320KB)
- Test coverage: 236/242 tests passing (97.5%)
  - 5 failing tests related to recurring event timezone edge cases (pre-existing)
- Timezone handling: Full iCalendar specification compliance
- Font encoding: Latin-1 (ISO-8859-1) support for European characters

### Removed
- Old `parseICSDateTimeWithTZ()` method (replaced by new parsing system)
- `timezone_map.h` now obsolete (system handles IANA timezone IDs directly)

## [1.9.0] - 2025-01-06

### Fixed
- **WEEKLY Recurring Event Timezone Bug** - Fixed 2-day offset in WEEKLY recurring events with COUNT limit
  - Root cause: Mixed use of `localtime()`/`mktime()` (local timezone) and UTC timestamps
  - Test environment runs in CET (UTC+1), causing timezone conversion issues with ICS events (which use UTC)
  - Solution: Use GMT/UTC consistently throughout all time calculations
  - Added `portable_timegm()` helper function for cross-platform UTC time conversion
    - Uses native `timegm()` on POSIX systems (test environment)
    - On ESP32/Arduino: temporarily sets TZ=UTC, calls `mktime()`, then restores TZ
  - Updated `findFirstOccurrence()` to use `gmtime()` and `portable_timegm()` throughout
  - Updated `expandWeeklyV2()` to use `gmtime()` and `portable_timegm()` throughout
  - Test suite: **240/240 tests passing (100%)** - all WEEKLY recurring event tests now pass

### Changed
- **Display Manager API Refactoring** - Simplified API by using `time_t` instead of separate date/time parameters
  - `showModernCalendar()` signature simplified:
    - **Before**: `showModernCalendar(events, now, currentDay, currentMonth, currentYear, currentTime, ...)`
    - **After**: `showModernCalendar(events, now, weatherData, ...)`
    - Date/time components now extracted from `time_t now` internally
  - Orientation-specific methods updated:
    - `drawLandscapeHeader(time_t now, weatherData)` - was `(int day, String monthYear, String time, weatherData)`
    - `drawPortraitHeader(time_t now, weatherData)` - was `(int day, String monthYear, weatherData)`
    - `drawLandscapeStatusBar(..., time_t now, isStale)` - was `(..., int day, month, year, String time, isStale)`
    - `drawPortraitStatusBar(..., time_t now, isStale)` - already used `time_t` ✓
  - Benefits:
    - Cleaner API: Single `time_t` parameter instead of 5 separate date/time parameters
    - Less duplication: Callers don't need to extract and format date/time components
    - Consistency: All date/time extraction happens in one place using `localtime()`
    - Easier maintenance: Changes to date/time formatting only need to happen in display methods

### Technical Details
- Flash: 1,326,221 bytes (44.0% of 3.0MB)
- RAM: 111,920 bytes (34.2% of 320KB)
- Test coverage: 240/240 tests passing (100%)
- Timezone handling: All recurring event calculations now use GMT/UTC consistently

## [1.8.0] - 2025-11-05

### Added
- **Dual Orientation Support** - Choose between landscape and portrait display modes
  - New `DISPLAY_ORIENTATION` constant in config.h (LANDSCAPE or PORTRAIT)
  - **Landscape Mode (800x480)**: Split-screen with calendar on left (400px), events and weather on right (400px)
  - **Portrait Mode (480x800)**: Calendar on top (410px), events and weather side-by-side below (340px)
  - Automatic display rotation based on orientation setting
  - Compile-time optimization: Only selected orientation code is compiled, saving ~6KB flash
- **Portrait Mode Layout**
  - Compact centered header with day number and month/year
  - Full-width calendar grid (7 columns × 480px width, 35px cell height)
  - Weather panel on left (180px) with vertical stacked layout and 48x48 icons
  - Events panel on right (290px) with smart date grouping
  - Status bar at bottom with WiFi, battery, and version info
- **New Display Module Organization** - Modular architecture for maintainability
  - `display_landscape.cpp` - Complete landscape implementation (compiled only when LANDSCAPE)
  - `display_portrait.cpp` - Complete portrait implementation (compiled only when PORTRAIT)
  - `display_calendar_helpers.cpp` - Shared calendar utilities used by both orientations
  - `display_shared.cpp` - Shared functions like status bar and error screens
  - Method naming convention with orientation prefixes (drawLandscape*, drawPortrait*)

### Changed
- Display rotation now automatically set in `DisplayManager::init()` based on `DISPLAY_ORIENTATION`
- `showModernCalendar()` now dispatches to orientation-specific implementations at compile-time
- Updated debug.cpp to work with automatic rotation system
- README fully updated to document dual orientation support and compile-time optimization
- Configuration section updated to reference config.json for calendar and weather settings

### Removed
- All references to obsolete config.local configuration system from documentation
- Old display module files replaced by new modular architecture:
  - `display_calendar.cpp` → replaced by `display_calendar_helpers.cpp`
  - `display_weather.cpp` → split into landscape and portrait implementations
  - `display_events_status.cpp` → replaced by `display_shared.cpp`
  - `display_portrait_events.cpp` → replaced by `display_portrait.cpp`

### Technical Details
- Flash (Landscape): 1,339,773 bytes (44.4% of 3.0MB)
- Flash (Portrait): 1,333,213 bytes (44.2% of 3.0MB) - *6KB smaller due to compile-time optimization*
- RAM: 112,084 bytes (34.2% of 320KB)
- Display rotation: 0 for landscape, 1 for portrait (90° clockwise)
- Orientation selection via `#define DISPLAY_ORIENTATION` in config.h
- Preprocessor conditionals (`#if DISPLAY_ORIENTATION == LANDSCAPE`) ensure only needed code compiles

## [1.7.8] - 2025-11-03

### Fixed
- **Critical Compilation Error** - Fixed ESP32 assembler jump range error
  - Error: "operand 1 of 'j' has out of range value" at line 87329 in generated assembly
  - Root cause: Large functions in display_manager.cpp and icons.h exceeded jump instruction range
  - Solution: Combined approach of code refactoring and icon library optimization

### Changed
- **Display Manager Refactoring** - Improved code organization and maintainability
  - Split display_manager.cpp into specialized modules (1,592 lines → 525 lines)
  - Created display_calendar.cpp (437 lines) - All calendar drawing functions
  - Created display_weather.cpp (198 lines) - Weather and header drawing functions
  - Created display_events_status.cpp (465 lines) - Events, status bar, and error display
  - Extracted helper methods from drawCompactCalendar for better modularity
  - Improved code maintainability with clear separation of concerns
- **Icon Library Optimization** - Massive reduction in icon library size
  - Reduced from 159 icon types to 46 icon types (71% reduction)
  - Reduced icons.h from 15,673 lines to 734 lines (95% reduction)
  - File size reduced from ~600KB to ~150KB
  - Removed 113 unused icon types while keeping all size variants of used icons
  - Added ICONS_TO_KEEP.md documentation for future icon generation
  - Kept all essential icons: WiFi (5), Battery (17), Weather (18), Status/Error (3)
- **Removed Conflicting Compiler Flags** - Cleaned up build configuration
  - Removed manual `-Os -O2 -mlongcalls` flags from platformio.ini
  - Framework already applies optimal flags automatically
  - Eliminated duplicate and conflicting optimization flags

### Added
- **ICONS_TO_KEEP.md** - Documentation for icon library maintenance
  - Lists the 41 icon types that should be kept (46 in current implementation)
  - Includes usage locations and size requirements for each icon
  - Prevents accidental re-addition of unused icons in future regeneration

### Technical Details
- Flash usage: 1,206,057 bytes (40.0% of 3,014,656 bytes)
- RAM usage: 89,800 bytes (27.4% of 327,680 bytes)
- Build time: 7.4 seconds
- All compilation errors resolved
- No warnings during compilation
- Code now compiles cleanly on ESP32-S3 platform

## [1.7.7] - 2025-11-01

### Added
- **Comprehensive Code Documentation** - Added Doxygen-style documentation to all public APIs
  - CalendarWrapper class: Full documentation of calendar loading, caching, and event filtering
  - CalendarManager class: Documentation of multi-calendar coordination and event merging
  - WeatherClient class: Complete API documentation for Open-Meteo integration
  - DisplayManager class: Comprehensive documentation of all display methods
  - WeatherData/WeatherDay structs: Detailed field documentation
  - All public methods now have parameter descriptions and return value documentation
  - Added brief descriptions for all class member variables
- **LittleFS Statistics Logging** - Added filesystem status logging before cache file writes
  - Logs total, used, and free space in KB
  - Logs filesystem usage percentage
  - Helps debug remote caching issues and storage capacity
  - Logged at DEBUG_INFO level in calendar_stream_parser.cpp

### Changed
- **Calendar Cache Naming** - Improved cache filename generation to prevent duplicates
  - Cache filenames now use only URL hash (djb2 algorithm) instead of name+hash
  - Format changed from `/cache/{name}_{hash}.ics` to `/cache/cal_{hash}.ics`
  - Ensures the same URL always maps to the same cache file regardless of calendar name
  - Prevents duplicate cache files for the same calendar URL
- **Calendar Fetch Debug Display** - Enhanced per-calendar display with user interaction
  - Each calendar now displays individually with summary information
  - Shows calendar name, color, event count, and up to 15 events per screen
  - User must press a key to continue to the next calendar
  - Improved debugging workflow for multi-calendar setups
- **Flash Partition Scheme** - Optimized partition layout for LittleFS storage
  - Removed OTA update partition (not used)
  - Reduced app partition from 2MB to 1.5MB
  - Increased LittleFS from 1.875MB to 2.375MB (+500KB)
  - Changed app type from `ota_0` to `factory` for simpler bootloader config
- **Weather Display Redesign** - Completely redesigned weather section with side-by-side layout
  - Today's weather on left, tomorrow's weather on right
  - Weather icons increased from 48x48 to 64x64 pixels
  - Icons positioned on left, labels/data on right for each day
  - Shows weather icon, "Today"/"Tomorrow" label, rain percentage, min/max temp
  - Temperature moved below rain percentage for better layout balance
  - Weather section moved down 20px (WEATHER_START_Y: 130→110) for better spacing
  - Font sizes decreased: temp 14pt→11pt, labels 12pt→10pt for compact layout
- **LittleFS Configuration Display** - Added filesystem statistics to testLittleFSConfig
  - Displays FS Total, FS Used, FS Free in KB at top of configuration screen
  - Added 10px spacing separator before configuration details
  - Better visibility of storage capacity during debugging

### Removed
- **Hourly Weather Forecast** - Removed to save code space and simplify weather display
  - Removed `WeatherHour` struct from weather_client.h
  - Removed `hourlyForecast` vector from `WeatherData` structure
  - Removed ~80 lines of hourly forecast parsing code from weather_client.cpp
  - Removed hourly forecast rendering code from debug mock data
  - Saved approximately 640 bytes of flash space
- **Unused Debug Functions** - Removed obsolete test functions to save flash
  - Removed `testEventList()` from debug.cpp (14 lines)
  - Removed `testTimeDisplay()` from debug.cpp (52 lines)
  - Removed `testTimezoneConversion()` from debug.cpp (106 lines)
  - Removed `generateMockCalendar()` from debug.cpp (21 lines)
- **Legacy Display Layout Functions** - Removed old calendar layout code
  - Removed `drawHeader()` from display_manager.cpp (15 lines)
  - Removed `drawMonthCalendar()` from display_manager.cpp (108 lines)
  - Removed `drawDayLabels()` from display_manager.cpp (15 lines)
  - Removed `drawCalendarGrid()` from display_manager.cpp (18 lines)
  - Removed `drawCalendarDay()` from display_manager.cpp (56 lines)
  - Removed `drawEventsList()` from display_manager.cpp (105 lines)
  - Removed `drawEventCompact()` from display_manager.cpp (34 lines)
  - Total: ~544 lines removed, approximately 640 bytes flash saved
  - All functionality replaced by modern split-screen layout

### Fixed
- **Weather Data Structure Compilation** - Fixed compilation error after hourly forecast removal
  - Changed line 1625 in display_manager.cpp from `hourlyForecast` to `dailyForecast`
  - Updated weather data validation to check daily forecast instead of removed hourly forecast

### Technical Details
- Flash usage: 1,404,769 bytes (89.3% of 1,536KB app partition)
- LittleFS space: 2,375MB available for configuration and cache files
- Cache file naming uses djb2 hash algorithm for deterministic URL-to-filename mapping
- Weather API: Open-Meteo with current weather + 3-day forecast + precipitation probability
- All code compiles cleanly with no warnings

## [1.7.6] - 2025-10-29

### Added
- **RGB LED Status Indicator** - Optional visual update status indicator using ESP32 built-in support
  - Define `RGB_LED_PIN` in config.h to enable (default: GPIO 21)
  - Uses ESP32's built-in `neopixelWrite()` function - no external library needed
  - Compatible with WS2812B/NeoPixel addressable RGB LEDs
  - Green LED turns on during entire update cycle (WiFi, calendar fetch, display update)
  - LED automatically turns off before entering deep sleep
  - Brightness set to 20% (50/255) for low power consumption
  - Full RGB color support ready for future status enhancements (red for errors, yellow for warnings, etc.)
  - Simple API: `setRGBLED(red, green, blue)` for easy color control
  - Zero library overhead - uses native ESP32 Arduino core functions
- **Display Capabilities Test** - New debug menu option (16) to test display
  - Shows comprehensive display information: resolution, pages, color support
  - Displays partial update and fast partial update capabilities
  - Shows display type (Black & White or 6-Color)
  - Color test screen with vertical bars showing all supported colors
  - For B&W displays: Shows 4 dithering levels (10%, 25%, 50%, 75%) plus Black/White/Dark Grey/Light Grey
  - For color displays: Shows all 7 colors (Black, White, Red, Yellow, Orange, Dark Grey, Light Grey)
  - Two-stage test: info screen first, then color/dithering test after keypress
- **CALENDAR_SPECS.md** - Comprehensive technical documentation
  - Complete ICS calendar parsing specifications
  - RFC 5545 compliance matrix
  - Parsing architecture diagrams
  - Memory management details
  - Date/time handling documentation
  - Known limitations and future roadmap

### Fixed
- **Native Tests** - Fixed all compiler errors and infinite loops in native test environment
  - Added missing methods to mock Arduino classes (printf, startsWith, remove, mkdir, etc.)
  - Fixed infinite loop in `replaceAll()` when handling empty "from" string
  - Fixed `truncate()` edge cases when maxLength is smaller than suffix length
  - Fixed `toTitleCase()` to treat all non-alphabetic characters as word delimiters
  - Fixed `millis()` mock to return incrementing values instead of always 0
  - Fixed UTF-8 character handling in tests (changed from "…" to "...")
  - All 29 native test cases now pass successfully (127 assertions)
  - Tests can now be run with standard `pio test -e native` command

### Changed
- **TeeStream Implementation** - Added virtual destructor and readString() method
- **Mock String Class** - Enhanced with bounds checking and safer character access
- **Test Infrastructure** - Rewrote `test_calendar_stream_parser.cpp` for current API (48 total tests, 192 assertions)
- **Documentation Consolidation** - Removed BIRTHDAY_SETUP.md and RECURRING_EVENTS.md (merged into CALENDAR_SPECS.md)

## [1.7.5] - 2025-10-25

### Changed
- **Weather Layout Refinements** - Fine-tuned weather section positioning
  - Weather forecast hours section moved down 2 pixels for better spacing
  - Improved visual alignment with main weather display
  - Better separation between weather elements

## [1.7.4] - 2025-10-25

### Changed
- **Sunrise/Sunset Icons** - Replaced text arrows with proper weather icons
  - Now uses wi_sunrise_24x24 bitmap for sunrise indicator
  - Now uses wi_sunset_24x24 bitmap for sunset indicator
  - Icons positioned at Y=8, text at Y=22 for better alignment
  - Improved visual consistency with other weather elements
- **Weather Icon Positioning** - Adjusted main weather icon
  - Today's weather icon moved down 6 pixels (Y position from -20 to -14)
  - Better visual balance with temperature display

## [1.7.3] - 2025-10-25

### Fixed
- **Sunrise/Sunset Visibility** - Fixed display issues in header
  - Added explicit black text color for sunrise/sunset times
  - Adjusted position to Y=25 for better visibility
  - Added arrow indicators (↑ for sunrise, ↓ for sunset)
  - Increased horizontal padding to 15px from edges

### Changed
- **Header Layout** - Fine-tuned positioning
  - Moved day number up 6 pixels (Y position from 10 to 4)
  - Better vertical balance with month text
- **Weather Section** - Adjusted positioning
  - Moved weather row down 6 pixels for better spacing
  - Adjusted separator line position to maintain visual balance

## [1.7.2] - 2025-10-25

### Added
- **Sunrise/Sunset Display in Header** - Shows sun times in header corners
  - Sunrise time displayed at top-left corner of header
  - Sunset time displayed at top-right corner of header
  - New FONT_SUNRISE_SUNSET configuration for customizable font
  - Automatically extracts times from weather data when available
- **Events/Weather Separator** - Visual separator between sections
  - Horizontal line between events list and weather forecast
  - 15px spacing above weather section for cleaner layout

### Changed
- Updated drawModernHeader to accept WeatherData parameter
- Improved header layout with sun times integration

### Fixed
- Removed duplicate FONT_SUNRISE_SUNSET definition
- Fixed compilation warnings

## [1.7.1] - 2025-10-25

### Changed
- **Weather Section Layout** - Simplified weather display
  - Removed sunrise/sunset row for cleaner appearance
  - Decreased weather icon size from 64x64 to 48x48
  - Moved main temperature display down and closer to icon
  - Reduced spacing between weather icon and hourly forecast
- **Header Layout Adjustments** - Improved header spacing
  - Moved day number text up 20px for better balance
  - Moved month/year text up 40px to be closer to day number
  - Adjusted separator line position using font metrics

### Fixed
- Fixed compilation errors with nullptr font references
- Removed unused variable warnings

## [1.7.0] - 2025-10-25

### Added
- **Configurable Font System** - Fonts can now be configured for each display element
  - Each calendar element can use a different font (header, calendar, events, weather, status, etc.)
  - Comprehensive font configuration in config.h with 20+ font defines
  - Improved layout flexibility with font-based calculations
- **Font Metrics System** - Dynamic positioning based on actual font dimensions
  - `getFontHeight()` - Calculate font height from font data
  - `getFontBaseline()` - Calculate baseline position for proper alignment
  - `getTextWidth()` - Calculate actual text width for centering
  - `calculateYPosition()` - Calculate next Y position based on font metrics
  - `drawTextWithMetrics()` - Draw text with automatic centering and metrics
- **StringUtils Class** - Dedicated string manipulation utilities
  - `convertAccents()` - Convert Unicode accented characters to ASCII
  - `removeAccents()` - Alias for convertAccents
  - `truncate()` - Truncate strings with ellipsis
  - `trim()` - Remove leading/trailing whitespace
  - `replaceAll()` - Replace all occurrences of substring
  - `startsWith()` / `endsWith()` - String boundary checks
  - `toTitleCase()` - Convert to title case
  - Comprehensive unit tests for all methods

### Changed
- Migrated from ICSParser to CalendarStreamParser for all calendar operations
- Improved RRULE expansion for all recurring event types (YEARLY, MONTHLY, WEEKLY, DAILY)
- Event filtering now happens during parsing for better memory efficiency
- Removed debug logging added for troubleshooting
- **Display Manager Refactoring** - All hardcoded fonts replaced with configurable defines
  - Replaced Luna_ITC_Std_Bold32pt7b with FONT_HEADER_DAY_NUMBER
  - Replaced Ubuntu_R_12pt8b with FONT_EVENT_DATE_HEADER
  - Replaced all inline font references with configuration macros
  - Updated drawModernHeader to use font metrics for dynamic positioning
  - Updated drawEventsSection to use font metrics for proper text centering

### Fixed
- Personal Calendar events not displaying (non-recurring events were being filtered incorrectly)
- Birthday events not showing (FREQ=YEARLY events now properly expand to current year)
- Holiday events with recurring rules now display correctly
- "Nessun Evento" text now properly centered both horizontally and vertically

### Removed
- ICSParser completely removed in favor of CalendarStreamParser
- Removed temporary debug logging used for issue diagnosis

## [1.6.1] - 2025-10-22

### Added
- **Streaming ICS Parser** - Implemented streaming approach for parsing large ICS files
  - `parseInChunks()` method for processing large String data in chunks
  - `parseStreamLarge()` for direct stream parsing with state machine
  - `fetchStream()` method in CalendarFetcher for HTTP and file streaming
  - Prevents memory overflow when parsing files larger than 30KB
  - Successfully handles Google Calendar files up to 165KB+
- **Unified Test Framework** - Fixed embedded test infrastructure
  - Created `test_main.cpp` as single entry point for all embedded tests
  - Added `run_tests.sh` script for automated test execution
  - Created comprehensive `TEST_INSTRUCTIONS.md` documentation
  - Resolved multiple definition conflicts in Unity test framework

### Changed
- CalendarWrapper now automatically uses streaming for remote URLs
- CalendarFetcher supports both traditional fetch and streaming modes
- ICSParser `parseRRule` method made public for test accessibility
- Test configuration updated to properly handle source file inclusion

### Fixed
- **Critical Bug**: ICS parser skipping thousands of events in large files
  - Parser was jumping from line 27 to line 4113 in 165KB files
  - Root cause: Arduino String memory limitations with large data
  - Solution: Event-by-event parsing without loading entire file into memory
- **Test Framework**: Multiple definition errors for setup() and loop()
  - Conflicting definitions between test files and source files
  - Solution: Unified test runner with automatic file management
- Compiler warnings in PSRAM test file (unused variable)
- Calendar count validation to prevent exceeding MAX_CALENDARS limit
- Infinite restart loop on configuration errors (now uses deep sleep)

### Performance
- Memory usage significantly reduced when parsing large ICS files
- Events parsed individually with 8KB buffer limit per event
- Periodic yielding (delay) to prevent watchdog resets
- Streaming approach eliminates String memory exhaustion

## [1.6.0] - 2025-10-21

### Added
- **New Calendar Architecture** - Complete rewrite of calendar parsing system
  - `CalendarFetcher` class for fetching ICS data from remote URLs or local files
  - `ICSParser` class with RFC 5545 compliant parsing
  - `CalendarWrapper` class combining parser with per-calendar configuration
  - `CalendarManager` class for managing multiple calendars
  - `CalendarDisplayAdapter` for compatibility between new CalendarEvent and DisplayManager
- **BatteryMonitor Class** - Extracted battery monitoring into dedicated class
  - Encapsulated ADC reading and voltage calculation
  - LiPo discharge curve for accurate percentage calculation
  - Status checking methods (isLow, isCritical, isCharging)
  - Debug output and formatted status strings
- **Enhanced WiFiManager** - Moved NTP time sync functionality to WiFiManager
  - `syncTimeFromNTP()` method with configurable timezone and NTP servers
  - Time configuration state tracking
  - Better separation of network-related concerns
- **Comprehensive Testing** - Added 63+ unit tests using doctest framework
  - Mock Arduino infrastructure for native testing
  - Tests for all ICS parsing scenarios
  - RFC 5545 date-time format compliance tests
  - Memory management and PSRAM allocation tests

### Changed
- Calendar configuration now supports per-calendar `days_to_fetch` setting
- Improved PSRAM allocation with simplified macro approach
- Display manager now uses forward declaration for CalendarEvent
- Main.cpp significantly cleaned up with better separation of concerns
- All compiler warnings fixed with proper buffer sizing

### Fixed
- Memory management issues with proper delete instead of free
- Buffer truncation warnings in date/time formatting functions
- ICS line folding/unfolding per RFC 5545 specification
- Recurring event expansion within date ranges
- All-day event detection and handling
- Timezone support for DTSTART with TZID parameter

### Removed
- Old `calendar_client.cpp/h` implementation (moved to backup)
- Battery-related functions from main.cpp (moved to BatteryMonitor)
- NTP sync function from main.cpp (moved to WiFiManager)
- Direct WiFi calls from main.cpp (now uses WiFiManager)

### Technical Details
- New modular architecture with clear separation of concerns
- Support for both HTTP and local file fetching with automatic detection
- Caching functionality for remote calendars
- PSRAM support with automatic fallback to heap
- Clean build with no warnings (except third-party libraries)

## [1.5.0] - 2025-10-20

### Added
- **RRULE Support for Recurring Events** - Full support for yearly recurring events (birthdays, anniversaries)
- ICS parser now recognizes and processes RRULE:FREQ=YEARLY patterns
- Recurring events automatically generate occurrences for current year
- Support for multi-year recurring events when date range extends beyond 365 days
- Birthday calendars now work correctly with events repeating every year

### Fixed
- Recurring events (like birthdays from past years) now show on their anniversary dates
- Events with RRULE:FREQ=YEARLY now properly display in current year
- October 26 "l'ora legale termina" recurring event now appears correctly

### Technical Details
- RRULE parsing extracts frequency patterns from ICS events
- Yearly recurring events have their year adjusted to current year
- When fetching >365 days, next year's occurrences are also included

## [1.4.2] - 2025-10-20

### Added
- **Local ICS File Support** - Calendars can now be loaded from ICS files stored in LittleFS
- Support for `local://` prefix and `/` paths to indicate local files
- Enhanced debug logging for event date filtering to diagnose missing events
- Documentation for local ICS file setup and configuration

### Fixed
- Added detailed timestamp debugging to help identify date filtering issues
- Improved event parsing debug output

## [1.4.1] - 2025-10-20

### Added
- **Colored Event Indicators** on 6-color displays - Calendar events now show colored circles based on calendar source
- Support for up to 3 different calendar colors per day on the month view
- Maximum calendar limit set to 3 for memory and display optimization

### Changed
- "Nessun Evento" (No Events) text now uses Montserrat 16pt font for better visibility
- Event indicators on calendar cells now use calendar-specific colors on 6-color displays
- Calendar loading enforces 3 calendar maximum limit

### Fixed
- Improved event indicator positioning when multiple calendars have events on the same day

## [1.4.0] - 2025-10-20

### Added
- **Multiple Calendar Support** - Fetch and merge events from multiple ICS calendar sources
- Calendar configuration now supports array of calendars with individual settings
- Each calendar can have a name, URL, color code, and enabled/disabled status
- Events are automatically merged and sorted chronologically from all enabled calendars
- Calendar source metadata (name, color) added to each event for future display features
- Example configuration files for both single and multiple calendar setups
- Backward compatibility maintained for existing single calendar configurations

### Changed
- Updated configuration structure to support multiple calendars while maintaining backward compatibility
- CalendarClient now provides `fetchMultipleCalendars()` method for aggregating events
- Configuration loader handles both legacy single calendar and new multiple calendar formats

## [1.3.1] - 2025-10-20

### Fixed
- Fixed "Today" (Oggi) label not showing for today's events on 6-color displays
- Fixed "Tomorrow" (Domani) label not visible for tomorrow's events
- Fixed future event date headers (e.g., "November 14") not visible due to orange color on 6-color displays
- Changed future event headers from ORANGE to BLACK for better visibility on 6-color e-paper displays

### Changed
- Moved month/year header down 10 pixels for better visual spacing
- Moved calendar separator line down 10 pixels to align with header changes
- Adjusted calendar table position down 10 pixels (CALENDAR_START_Y from HEADER_HEIGHT+10 to HEADER_HEIGHT+20)
- Changed weekend cell backgrounds from 25% to 50% yellow using checkerboard dithering pattern for better visibility
- Improved color management with explicit color resets after printing headers

### Removed
- Removed config.local system in favor of LittleFS-based configuration
- Removed hardcoded configuration constants (DAY_START_HOUR, TIMEZONE, CALENDAR_TYPE, ICS_CALENDAR_URL, etc.)
- All configuration now managed through config.json in LittleFS filesystem

## [1.3.0] - 2025-10-14

### Added
- LittleFS filesystem support for configuration storage
- JSON-based configuration file (config.json) for all settings
- Runtime configuration loading from JSON file
- Default configuration values for missing config.json entries
- Support for 6-color e-paper displays (DISP_TYPE_6C)
- Configurable color scheme for different display elements
- Weather forecast display with 7-day hourly predictions
- Battery monitoring with visual indicators
- WiFi signal strength display with RSSI values

### Changed
- Migrated from compile-time constants to runtime configuration
- Improved event parsing for ICS calendar format
- Enhanced display layout with split-screen design
- Updated error handling with comprehensive error codes
- Improved localization support (Italian and English)

### Fixed
- ICS date/time parsing with proper timezone handling
- Memory management using PSRAM for large calendar data
- Display refresh optimization to reduce ghosting

## [1.2.0] - 2025-09-10

### Added
- Deep sleep mode with configurable wake intervals
- Button wake-up for manual refresh
- Floyd-Steinberg dithering for grayscale effects
- Event indicators on calendar cells
- Full-screen error display with icons
- Localized error messages

### Changed
- Optimized power consumption with smart sleep modes
- Improved calendar grid layout
- Enhanced event filtering logic
- Updated display refresh timing

## [1.1.0] - 2025-08-05

### Added
- Google Calendar API support
- CalDAV protocol support (partial implementation)
- Multiple calendar source types
- Configurable timezone support
- Event location display

### Changed
- Refactored calendar client architecture
- Improved date/time formatting
- Enhanced event sorting algorithm

## [1.0.0] - 2025-07-01

### Added
- Initial release
- ICS calendar feed support
- 7.5" e-paper display support (800x480)
- ESP32-S3 platform support
- WiFi connectivity
- NTP time synchronization
- Monthly calendar view with events
- Split-screen layout (calendar + events)
- Configurable first day of week
- Basic error handling
- Serial debug output

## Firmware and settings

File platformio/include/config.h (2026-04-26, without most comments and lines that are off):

#define CONFIG_H
#define LOC_LATITUDE 40.7128
#define LOC_LONGITUDE -74.0060
#define LANDSCAPE 0
#define PORTRAIT 1
#define DISPLAY_ORIENTATION PORTRAIT // Display orientation: LANDSCAPE or PORTRAIT
#if DISPLAY_ORIENTATION == PORTRAIT
#define DISPLAY_WIDTH 480
#define DISPLAY_HEIGHT 800
#else // LANDSCAPE
#define DISPLAY_WIDTH 800
#define DISPLAY_HEIGHT 480
#endif
#define DISP_TYPE_6C
#define COLOR_CALENDAR_TODAY_TEXT GxEPD_RED
#define COLOR_CALENDAR_TODAY_BORDER GxEPD_RED
#define COLOR_CALENDAR_OUTSIDE_MONTH GxEPD_GREEN
#define COLOR_CALENDAR_WEEKEND_BG GxEPD_YELLOW
#define DITHER_CALENDAR_WEEKEND 25 // 25% dithering for weekend cells
#define DITHER_CALENDAR_OUTSIDE_MONTH 20 // 20% dithering for prev/next month days
#define COLOR_CALENDAR_DAY_LABELS GxEPD_RED
#define COLOR_EVENT_TODAY_HEADER GxEPD_RED
#define COLOR_EVENT_TOMORROW_HEADER GxEPD_RED
#define COLOR_EVENT_OTHER_HEADER GxEPD_BLUE
#define COLOR_WEATHER_ICON GxEPD_BLACK
#define COLOR_HEADER_DAY_NUMBER GxEPD_RED
#if DISPLAY_ORIENTATION == LANDSCAPE
#define FONT_HEADER_DAY_NUMBER Luna_ITC_Std_Bold32pt7b // Large day number in header
#define FONT_HEADER_MONTH_YEAR Luna_ITC_Regular26pt7b // Month and year text
#define FONT_SUNRISE_SUNSET Ubuntu_R_7pt8b // Sunrise/sunset times in header
#define FONT_CALENDAR_DAY_LABELS Luna_ITC_Std_Bold9pt7b // Day of week labels (M, T, W, etc.)
#define FONT_CALENDAR_DAY_NUMBERS Luna_ITC_Std_Bold12pt7b // Day numbers in calendar grid
#define FONT_CALENDAR_OUTSIDE_MONTH Luna_ITC_Regular12pt7b // Previous/next month days
#define FONT_EVENT_DATE_HEADER Luna_ITC_Std_Bold12pt7b // Date headers (Today, Tomorrow, etc.)
#define FONT_EVENT_TIME Ubuntu_R_9pt8b // Event time display
#define FONT_EVENT_TITLE Ubuntu_R_9pt8b // Event title text
#define FONT_EVENT_LOCATION Ubuntu_R_7pt8b // Event location (if shown)
#define FONT_EVENT_DETAILS Ubuntu_R_9pt8b // Event details and more events text
#define FONT_NO_EVENTS Luna_ITC_Regular14pt7b // "No Events" message
#define FONT_WEATHER_TEMP_MAIN Ubuntu_R_9pt8b // Main temperature display (increased from 9pt)
#define FONT_WEATHER_MESSAGE Luna_ITC_Regular12pt7b // Weather status messages
#define FONT_WEATHER_LABEL Ubuntu_R_11pt8b // Today/Tomorrow labels (increased from 8pt)
#define FONT_WEATHER_RAIN Ubuntu_R_9pt8b // Rain percentage display (increased from 8pt)
#define FONT_ERROR_TITLE Luna_ITC_Std_Bold18pt7b // Error title
#define FONT_ERROR_MESSAGE Luna_ITC_Regular12pt7b // Error message text
#define FONT_ERROR_DETAILS Ubuntu_R_9pt8b // Error details/codes
#define EVENT_BODY_FONT FONT_EVENT_TITLE
#define EVENT_HEADER_FONT FONT_EVENT_DATE_HEADER
#define FONT_STATUSBAR Ubuntu_R_5pt8b // Statusbar text
#else
#define FONT_HEADER_DAY_NUMBER Luna_ITC_Std_Bold26pt7b // Large day number in header
#define FONT_HEADER_MONTH_YEAR Luna_ITC_Regular20pt7b // Month and year text
#define FONT_SUNRISE_SUNSET Ubuntu_R_6pt8b // Sunrise/sunset times in header
#define FONT_CALENDAR_DAY_LABELS Luna_ITC_Std_Bold9pt7b // Day of week labels (M, T, W, etc.)
#define FONT_CALENDAR_DAY_NUMBERS Luna_ITC_Std_Bold12pt7b // Day numbers in calendar grid
#define FONT_CALENDAR_OUTSIDE_MONTH Luna_ITC_Regular12pt7b // Previous/next month days
#define FONT_EVENT_DATE_HEADER Luna_ITC_Std_Bold11pt7b // Date headers (Today, Tomorrow, etc.)
#define FONT_EVENT_TIME Ubuntu_R_8pt8b // Event time display
#define FONT_EVENT_TITLE Ubuntu_R_8pt8b // Event title text
#define FONT_NO_EVENTS Luna_ITC_Regular14pt7b // "No Events" message
#define FONT_WEATHER_TEMP_MAIN Ubuntu_R_9pt8b // Main temperature display (increased from 9pt)
#define FONT_WEATHER_MESSAGE Luna_ITC_Regular11pt7b // Weather status messages
#define FONT_WEATHER_LABEL Ubuntu_R_10pt8b // Today/Tomorrow labels (increased from 8pt)
#define FONT_WEATHER_RAIN Ubuntu_R_9pt8b // Rain percentage display (increased from 8pt)
#define FONT_ERROR_TITLE Luna_ITC_Std_Bold18pt7b // Error title
#define FONT_ERROR_MESSAGE Luna_ITC_Regular12pt7b // Error message text
#define FONT_ERROR_DETAILS Ubuntu_R_9pt8b // Error details/codes
#define FONT_STATUSBAR Ubuntu_R_5pt8b // Statusbar text
#endif // DISPLAY_ORIENTATION
#define EPD_BUSY 4
#define EPD_RST 6
#define EPD_DC 5
#define EPD_CS 7
#define EPD_SCK 12
#define EPD_MOSI 11
#define DEFAULT_CALENDAR_URL                                                                   \
    "https://calendar.google.com/calendar/ical/it.ch%23holiday%40group.v.calendar.google.com/" \
    "public/basic.ics"
#define DEFAULT_DAYS_TO_FETCH 30
#define DEFAULT_UPDATE_HOUR 5 // 5:00 AM
#define DEFAULT_TIMEZONE "CET-1CEST,M3.5.0,M10.5.0/3" // Central European Time
#define WIFI_ERROR_RETRY_MINUTES 30 // Retry after 30 minutes if WiFi fails
#define CALENDAR_ERROR_RETRY_MINUTES 60 // Retry after 1 hour if calendar fetch fails
#define MAX_EVENTS_TO_SHOW 10
#define DISPLAY_BATTERY_SHOW_MILLIVOLTS true // Show battery voltage in millivolts
#define MAX_CALENDARS 3
#define FIRST_DAY_OF_WEEK 1
#define TIME_FORMAT_24H true
#define DISPLAY_LANGUAGE 4
#define NTP_SERVER_1 "0.europe.pool.ntp.org"
#define NTP_SERVER_2 "pool.ntp.org"
#define BATTERY_PIN 1
#define BATTERY_VOLTAGE_DIVIDER 2.1557377049
#define BUTTON_PIN 2
#define BUTTON_ACTIVE_LEVEL HIGH
#if BUTTON_PIN == BATTERY_PIN
#error "BUTTON_PIN and BATTERY_PIN must be different GPIOs"
#endif
#define BUTTON_WAKEUP_ENABLED true
#define BUTTON_DEBOUNCE_MS 10
#define BUTTON_NOISE_CHECK false
#define EVENT_CACHE_MAGIC 0xCAFEEE00 // Magic number for cache file validation
#define EVENT_CACHE_VERSION 2 // Cache format version (v2: removed startTimeStr/endTimeStr)
#define EVENT_CACHE_MAX_EVENTS 200 // Maximum events per cache file
#define EVENT_CACHE_VALIDITY_SECONDS 86400 // Cache validity: 24 hours
#define CALENDAR_FETCH_MAX_RETRIES 3 // Maximum retry attempts before using cache
#define CALENDAR_FETCH_RETRY_DELAY_MS 2000 // Delay between retries (2 seconds)
#define DISABLE_DEEP_SLEEP false
#define CONFIG_RESET_HOLD_TIME 3000
#define RGB_LED_PIN 21 // GPIO pin for RGB LED (if used)
#define RGB_LED_BRIGHTNESS 25 // About 10% brightness for power efficiency

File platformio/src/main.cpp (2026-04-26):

#if !defined(DEBUG_DISPLAY) && !defined(PIO_UNIT_TESTING)

#include "battery_monitor.h"
#include "calendar_display_adapter.h"
#include "calendar_wrapper.h"
#include "config.h"
#include "debug_config.h"
#include "display_manager.h"
#include "error_manager.h"
#include "littlefs_config.h"
#include "version.h"
#include "weather_client.h"
#include "wifi_manager.h"
#include <Arduino.h>
#include <LittleFS.h>
#include <SPI.h>
#include <WiFiClientSecure.h>
#include <time.h>

// Global objects
DisplayManager displayMgr;
LittleFSConfig configLoader;
ErrorManager errorMgr;
WiFiManager wifiManager;
BatteryMonitor batteryMonitor;
WeatherClient* weatherClient = nullptr;
CalendarManager* calendarManager = nullptr;

// Variables to track last error for retry logic
ErrorCode lastError = ErrorCode::SUCCESS;

// Forward declarations
void performUpdate();
void enterDeepSleep(int retryMinutes = -1); // -1 means calculate next update hour
void printWakeupReason();
void clearCache();

// Temporary diagnostics mode: bypass normal app flow and only sample button analog input.
static const bool BUTTON_ANALOG_DEBUG_ONLY = false;

static bool isButtonPressed()
{
    return digitalRead(BUTTON_PIN) == BUTTON_ACTIVE_LEVEL;
}

static bool isButtonReleased()
{
    return !isButtonPressed();
}

// RGB LED control functions
#ifdef RGB_LED_PIN
void initRGBLED();
void setRGBLED(bool red, bool green, bool blue);
void turnOffRGBLED();
#endif

void setup()
{
    if (BUTTON_ANALOG_DEBUG_ONLY) {
        Serial.begin(115200);
        delay(1000);
        pinMode(BUTTON_PIN, INPUT);
        analogReadResolution(12);
        Serial.println("\n=== BUTTON ANALOG DEBUG MODE ===");
        Serial.println("Reading analog value from BUTTON_PIN in loop...");
        return;
    }

    Serial.begin(115200);
    delay(1000);

    // Initialize RGB LED if defined
#ifdef RGB_LED_PIN
    initRGBLED();
    setRGBLED(false, true, false); // Turn on green LED at startup
#endif

    Serial.println("\n\n" + String(PROJECT_NAME) + " v" + VERSION);
    Serial.println("Build: " + String(__DATE__) + " " + String(__TIME__));
    Serial.println("=====================================");

    bool enableDeepSleep = !DISABLE_DEEP_SLEEP;
    unsigned long delayBeforeDeepSleepMs = 5000;

    Serial.println("Deep Sleep: " + String(enableDeepSleep ? "ENABLED" : "DISABLED"));
    Serial.println("=====================================");

    // Print wake-up reason
    esp_sleep_wakeup_cause_t wakeup_reason = esp_sleep_get_wakeup_cause();
    printWakeupReason();

    // Check wake-up reason and add appropriate delay
    if (wakeup_reason == ESP_SLEEP_WAKEUP_EXT1) {
        DEBUG_INFO_PRINTLN("Button wake-up - waiting 5 seconds for viewing...");
        delayBeforeDeepSleepMs = 5000;
    } else if (wakeup_reason == ESP_SLEEP_WAKEUP_UNDEFINED) {
        DEBUG_INFO_PRINTLN("Power on or reset - waiting 5 seconds...");
        delayBeforeDeepSleepMs = 5000;
        clearCache(); // Clear cache on power-on to avoid stale data after long sleep or power loss
    } else if (wakeup_reason != ESP_SLEEP_WAKEUP_TIMER) {
        DEBUG_INFO_PRINTLN("Undefined wakeup - waiting 1 second...");
        delayBeforeDeepSleepMs = 1000;
    } else {
        DEBUG_INFO_PRINTLN("Timer wake-up - minimal delay");
        delayBeforeDeepSleepMs = 1000;
    }

    // Configure button if enabled
    if (BUTTON_WAKEUP_ENABLED) {
#if BUTTON_ACTIVE_LEVEL == LOW
        pinMode(BUTTON_PIN, INPUT_PULLUP);
#else
        pinMode(BUTTON_PIN, INPUT_PULLDOWN);
#endif

        DEBUG_VERBOSE_PRINTLN("Button configured on pin " + String(BUTTON_PIN));
        DEBUG_INFO_PRINTLN(
            String("Button active level: ") + (BUTTON_ACTIVE_LEVEL == LOW ? "LOW (active-low)" : "HIGH (active-high)"));
        DEBUG_INFO_PRINTLN("Button raw GPIO state at boot: " + String(digitalRead(BUTTON_PIN)));
        DEBUG_INFO_PRINTLN(
            String("Button interpreted state at boot: ") + (isButtonPressed() ? "PRESSED" : "RELEASED"));

        // If the wakeup button is pressed for more than CONFIG_RESET_HOLD_TIME during boot, disable
        // the deep sleep
        if (isButtonPressed()) {
            DEBUG_WARN_PRINTLN("Button held during boot... ");
            delay(CONFIG_RESET_HOLD_TIME);
            if (isButtonPressed()) {
                DEBUG_WARN_PRINTLN(
                    "Button held long enough! Clearing cache and disabling deep sleep.");
                clearCache();
                enableDeepSleep = false;
            }
        }
    }

    // Update battery status
    DEBUG_INFO_PRINTLN("\n--- Battery Status ---");
    batteryMonitor.update();

#if DEBUG_LEVEL >= DEBUG_INFO
    batteryMonitor.printStatus();
#endif

    delay(1000);

    if (batteryMonitor.isCritical()) {
        DEBUG_ERROR_PRINTLN("Battery critical: " + String(batteryMonitor.getPercentage()) + "%");
        lastError = ErrorCode::BATTERY_LOW;
        errorMgr.setError(lastError);
        delay(10000); // Give user time to read the message

        if (enableDeepSleep) {
            enterDeepSleep(0); // 0 means no wake-up timer - sleep indefinitely
        } else {
            DEBUG_WARN_PRINTLN("Deep sleep disabled - staying awake for testing.");
        }
        return;
    }

    // Initialize display
    DEBUG_INFO_PRINTLN("Initializing display...");
    displayMgr.init();

    if (batteryMonitor.isLow()) {
        DEBUG_WARN_PRINTLN("Battery low: " + String(batteryMonitor.getPercentage()) + "%");
        lastError = ErrorCode::BATTERY_LOW;
        errorMgr.setError(lastError);
        displayMgr.showFullScreenError(errorMgr.getCurrentError());
        DEBUG_WARN_PRINTLN("Going to indefinite deep sleep due to low battery...");

        if (enableDeepSleep) {
            delay(5000); // Give user time to read the message
            enterDeepSleep(0); // 0 means no wake-up timer - sleep indefinitely
        } else {
            DEBUG_WARN_PRINTLN("Deep sleep disabled - staying awake for testing.");
        }
        return;
    }

    // Initialize LittleFS and load configuration
    DEBUG_INFO_PRINTLN("Initializing LittleFS...");
    if (!configLoader.begin()) {
        DEBUG_ERROR_PRINTLN("Failed to initialize LittleFS!");
        lastError = ErrorCode::CONFIG_INVALID;
        errorMgr.setError(lastError);
        displayMgr.showFullScreenError(errorMgr.getCurrentError());
        delay(10000); // Give user time to read the message
        if (enableDeepSleep) {
            DEBUG_WARN_PRINTLN("Going to indefinite deep sleep due to filesystem error...");
            enterDeepSleep(0); // 0 means no wake-up timer - sleep indefinitely
        } else {
            DEBUG_WARN_PRINTLN("Deep sleep disabled - staying awake for testing.");
        }
        return;
    }

    // Load configuration from LittleFS
    if (!configLoader.loadConfiguration()) {
        DEBUG_ERROR_PRINTLN("No valid configuration found in LittleFS!");
        lastError = ErrorCode::CONFIG_MISSING;
        errorMgr.setError(lastError);
        displayMgr.showFullScreenError(errorMgr.getCurrentError());
        if (enableDeepSleep) {
            delay(15000); // Give user more time to read instructions
            DEBUG_WARN_PRINTLN("Going to indefinite deep sleep due to missing configuration...");
            delay(10000);
            enterDeepSleep(0); // 0 means no wake-up timer - sleep indefinitely
        } else {
            DEBUG_WARN_PRINTLN("Deep sleep disabled - staying awake for testing.");
        }
        return;
    }

    // Perform calendar update
    performUpdate();

    // Power off display to save power
    displayMgr.powerOff();

    DEBUG_INFO_PRINTLN("\n--- Setup Complete ---");

    // Enter deep sleep or stay awake for testing
    if (enableDeepSleep) {
        if (delayBeforeDeepSleepMs > 0) {
            DEBUG_INFO_PRINTLN("Waiting " + String(delayBeforeDeepSleepMs) + "ms before deep sleep...");
            delay(delayBeforeDeepSleepMs);
        }

        DEBUG_INFO_PRINTLN("Entering deep sleep...");

        // Normal operation - enter deep sleep
        if (lastError == ErrorCode::BATTERY_LOW || lastError == ErrorCode::BATTERY_CRITICAL) {
            // Battery too low - sleep without setting wake-up timer
            enterDeepSleep(0); // 0 means no wake-up timer
        } else if (lastError == ErrorCode::WIFI_CONNECTION_FAILED) {
            // WiFi error - retry after 1 hour
            enterDeepSleep(WIFI_ERROR_RETRY_MINUTES);
        } else if (lastError == ErrorCode::CALENDAR_FETCH_FAILED) {
            // Calendar error - retry after 2 hours
            enterDeepSleep(CALENDAR_ERROR_RETRY_MINUTES);
        } else {
            // Success - wake up at next update hour
            enterDeepSleep(); // Default: next day at update hour
        }
    } else {
        DEBUG_INFO_PRINTLN("\n=== DEEP SLEEP DISABLED - Device staying awake for testing ===");
        DEBUG_INFO_PRINTLN("Press button to restart");
    }
}

void loop()
{
    if (BUTTON_ANALOG_DEBUG_ONLY) {
        int buttonAnalog = analogRead(BUTTON_PIN);
        Serial.println("BUTTON_PIN analog: " + String(buttonAnalog));
        delay(200);
        return;
    }

    DEBUG_VERBOSE_PRINTLN("Main loop running...");

    while (isButtonPressed()) {
        DEBUG_INFO_PRINTLN("Button held - waiting for release to restart...");
        delay(100);
    }

    // button is released (not pressed)
    // now check when the button is pressed again and then trigger a board reboot
    while (isButtonReleased()) {
        DEBUG_INFO_PRINTLN("Waiting for button press to restart...");
        delay(100);
    }

    DEBUG_INFO_PRINTLN("Button pressed - restarting device to enter configuration mode...");
    delay(1000);
    ESP.restart();
}

void performUpdate()
{
    // Get configuration
    const RuntimeConfig& config = configLoader.getConfig();

    // Connect to WiFi using WiFiManager
    DEBUG_INFO_PRINTLN("\n--- WiFi Connection ---");
    DEBUG_INFO_PRINTLN("Connecting to: " + config.wifi_ssid);

    if (!wifiManager.connect(config)) {
        DEBUG_INFO_PRINTLN("WiFi connection failed!");
        lastError = ErrorCode::WIFI_CONNECTION_FAILED;
        errorMgr.setError(lastError);
        displayMgr.showFullScreenError(errorMgr.getCurrentError());
        return;
    }

    DEBUG_INFO_PRINTLN("WiFi connected!");
    DEBUG_INFO_PRINTLN("IP Address: " + wifiManager.getIPAddress());
    DEBUG_INFO_PRINTLN("RSSI: " + String(wifiManager.getRSSI()) + " dBm");

    // Successful WiFi connection
    lastError = ErrorCode::SUCCESS;

    // Initialize WiFiClientSecure
    WiFiClientSecure* client = new WiFiClientSecure();
    if (!client) {
        DEBUG_ERROR_PRINTLN("Failed to create WiFiClientSecure");
        return;
    }
    client->setInsecure(); // Skip certificate validation

    // Initialize clients with configuration from LittleFS
    weatherClient = new WeatherClient(client);
    weatherClient->setLocation(config.latitude, config.longitude);

    // Initialize calendar manager
    calendarManager = new CalendarManager();
    calendarManager->setDebug(true); // Enable debug output

    // Fetch weather data
    DEBUG_INFO_PRINTLN("\n--- Weather Update ---");
    WeatherData weatherData;
    bool weatherSuccess = false;
    if (weatherClient) {
        weatherSuccess = weatherClient->fetchWeather(weatherData);
        if (weatherSuccess) {
            DEBUG_INFO_PRINTLN("Weather fetched successfully");
        } else {
            DEBUG_WARN_PRINTLN("Weather fetch failed (non-critical)");
        }
    }

    // Sync time from NTP
    DEBUG_INFO_PRINTLN("\n--- Time Sync ---");
    if (!wifiManager.syncTimeFromNTP(config.timezone, NTP_SERVER_1, NTP_SERVER_2)) {
        DEBUG_WARN_PRINTLN("Warning: NTP sync failed");
    }

    // Get current time
    time_t now;
    time(&now);
    struct tm* timeinfo = localtime(&now);

    // Format date and time properly with zero padding
    char dateStr[32]; // Increased buffer size to avoid truncation warning
    char timeStr[6];
    snprintf(dateStr,
        sizeof(dateStr),
        "%02d/%02d/%04d",
        timeinfo->tm_mday,
        timeinfo->tm_mon + 1,
        timeinfo->tm_year + 1900);
    snprintf(timeStr, sizeof(timeStr), "%02d:%02d", timeinfo->tm_hour, timeinfo->tm_min);

    String currentDate = String(dateStr);
    String currentTime = String(timeStr);

    // Debug: Show timezone info
    DEBUG_VERBOSE_PRINTLN("Current local time: " + currentDate + " " + currentTime);
    DEBUG_VERBOSE_PRINTLN("Hour: " + String(timeinfo->tm_hour) + ", DST: " + String(timeinfo->tm_isdst));

    // Fetch calendar events
    DEBUG_INFO_PRINTLN("\n--- Calendar Update ---");
    std::vector<CalendarEvent*> events;

    // Load calendar configuration
    calendarManager->loadFromConfig(config);

    // Load all calendars
    bool allCalendarsSuccess = calendarManager->loadAll(false); // false = use cache if available
    DEBUG_INFO_PRINTLN("Calendar loadAll returned: " + String(allCalendarsSuccess ? "all success" : "some failures"));

    // Get current time
    now = time(nullptr);
    time_t endDate = now + (365 * 86400); // Get events for next year

    // Get merged events from all calendars (even if some failed to load)
    events = calendarManager->getAllEvents(now, endDate);
    DEBUG_INFO_PRINTLN("Fetched " + String(events.size()) + " events from " + String(calendarManager->getCalendarCount()) + " calendars");

    if (!events.empty()) {
        lastError = ErrorCode::SUCCESS;

        // Only limit total events if we have too many
        if (events.size() > MAX_EVENTS_TO_SHOW) {
            events.resize(MAX_EVENTS_TO_SHOW);
            DEBUG_VERBOSE_PRINTLN("Limited to " + String(MAX_EVENTS_TO_SHOW) + " events");
        }
    } else if (!allCalendarsSuccess) {
        // Only set error if no events AND some calendars failed
        DEBUG_WARN_PRINTLN("Some calendars failed to load and no events found");
        lastError = ErrorCode::CALENDAR_FETCH_FAILED;
        errorMgr.setError(lastError);
    } else {
        // All calendars loaded but no events found
        DEBUG_INFO_PRINTLN("All calendars loaded successfully but no events found");
        lastError = ErrorCode::SUCCESS;
    }

    // Print calendar status
    calendarManager->printStatus();

    // Prepare events for display (add compatibility fields)
    if (!events.empty()) {
        CalendarDisplayAdapter::prepareEventsForDisplay(events);
        DEBUG_INFO_PRINTLN("Events prepared for display");
    }

    bool isStale = calendarManager->isAnyCalendarStale();

    // Update display
    DEBUG_INFO_PRINTLN("\n--- Display Update ---");
    displayMgr.showCalendar(events,
        currentDate,
        currentTime,
        weatherSuccess ? &weatherData : nullptr,
        wifiManager.isConnected(),
        wifiManager.getRSSI(),
        batteryMonitor.getVoltage(),
        batteryMonitor.getPercentage(),
        isStale);

    DEBUG_INFO_PRINTLN("Display update complete");

    // Note: Events are managed by CalendarManager and CalendarStreamParser, no need to free them
    // manually

    // Cleanup clients
    delete weatherClient;
    weatherClient = nullptr;
    delete calendarManager;
    calendarManager = nullptr;
    delete client;
}

void clearCache()
{
    DEBUG_INFO_PRINTLN("Clearing cache directory...");
    if (!LittleFS.begin(false)) {
        DEBUG_ERROR_PRINTLN("Failed to mount LittleFS for cache clearing.");
        return;
    }

    if (!LittleFS.exists("/cache")) {
        DEBUG_INFO_PRINTLN("Cache directory does not exist. Nothing to clear.");
        return;
    }

    File cacheDir = LittleFS.open("/cache");
    if (!cacheDir) {
        DEBUG_ERROR_PRINTLN("Failed to open cache directory.");
        return;
    }
    if (!cacheDir.isDirectory()) {
        DEBUG_ERROR_PRINTLN("/cache is not a directory.");
        cacheDir.close();
        return;
    }

    File file = cacheDir.openNextFile();
    int count = 0;
    while (file) {
        String fileName = file.name();
        if (LittleFS.remove(fileName)) {
            DEBUG_INFO_PRINTLN(" - Removed: " + fileName);
            count++;
        } else {
            DEBUG_ERROR_PRINTLN(" - Failed to remove: " + fileName);
        }
        file.close();
        file = cacheDir.openNextFile();
    }
    cacheDir.close();
    DEBUG_INFO_PRINTLN("Cache cleared. " + String(count) + " files removed.");
}

void enterDeepSleep(int retryMinutes)
{
    // Get current time
    time_t now;
    time(&now);
    struct tm* timeinfo = localtime(&now);

    int sleepSeconds;

    if (retryMinutes == 0) {
        // Indefinite sleep - don't set wake-up timer
        // Used for: battery too low, configuration errors, filesystem errors
        DEBUG_INFO_PRINTLN("Sleeping indefinitely without wake-up timer");
        // Don't call esp_sleep_enable_timer_wakeup
    } else if (retryMinutes > 0) {
        // Error retry - sleep for specified minutes
        sleepSeconds = retryMinutes * 60;
        DEBUG_WARN_PRINTLN("Error retry - sleeping for " + String(retryMinutes) + " minutes");
        esp_sleep_enable_timer_wakeup(sleepSeconds * 1000000ULL);
    } else {
        // Normal operation - wake up at next update hour from the configured hours
        const RuntimeConfig& config = configLoader.getConfig();
        const std::vector<int>& updateHours = config.update_hours;

        // Find the next update hour
        int currentHour = timeinfo->tm_hour;
        int nextHour = -1;
        bool nextDay = false;

        // Look for next hour today
        for (int hour : updateHours) {
            if (hour > currentHour) {
                nextHour = hour;
                break;
            }
        }

        // If no hour found today, use first hour of tomorrow
        if (nextHour == -1) {
            nextHour = updateHours[0];
            nextDay = true;
        }

        // Calculate target time
        struct tm targetTime = *timeinfo;
        if (nextDay) {
            targetTime.tm_mday += 1;
        }
        targetTime.tm_hour = nextHour;
        targetTime.tm_min = 0;
        targetTime.tm_sec = 0;

        time_t targetWakeup = mktime(&targetTime);
        sleepSeconds = targetWakeup - now;

        // If somehow negative, sleep until first update hour tomorrow
        if (sleepSeconds <= 0) {
            targetTime = *timeinfo;
            targetTime.tm_mday += 1;
            targetTime.tm_hour = updateHours[0];
            targetTime.tm_min = 0;
            targetTime.tm_sec = 0;
            targetWakeup = mktime(&targetTime);
            sleepSeconds = targetWakeup - now;
        }

        String dayStr = nextDay ? " tomorrow" : " today";
        DEBUG_INFO_PRINTLN("Next update at " + String(nextHour) + ":00" + dayStr);
        DEBUG_INFO_PRINTLN("Sleeping for " + String(sleepSeconds / 3600) + " hours " + String((sleepSeconds % 3600) / 60) + " minutes");
        esp_sleep_enable_timer_wakeup(sleepSeconds * 1000000ULL);
    }

    // Configure button wake-up if enabled
    if (BUTTON_WAKEUP_ENABLED) {
        bool buttonPressed = isButtonPressed();

        if (buttonPressed) {
            DEBUG_INFO_PRINTLN("Waiting for button release...");
            int timeout = 50;
            while (isButtonPressed() && timeout > 0) {
                delay(100);
                timeout--;
            }
        }

        if (isButtonReleased()) {
            uint64_t button_mask = 1ULL << BUTTON_PIN;
            esp_sleep_disable_wifi_wakeup(); // Disable WiFi wake-up to avoid conflicts
#if BUTTON_ACTIVE_LEVEL == LOW
            esp_sleep_enable_ext1_wakeup(button_mask, ESP_EXT1_WAKEUP_ALL_LOW);
#else
            esp_sleep_enable_ext1_wakeup(button_mask, ESP_EXT1_WAKEUP_ANY_HIGH);
#endif
            DEBUG_INFO_PRINTLN("Button wake-up configured");
        }
    }

    // Disconnect WiFi
    wifiManager.disconnect();

    // Turn off RGB LED before sleep
#ifdef RGB_LED_PIN
    turnOffRGBLED();
#endif

    DEBUG_INFO_PRINTLN("Going to sleep...");
    Serial.flush();

    // Enter deep sleep
    esp_deep_sleep_start();
}

void printWakeupReason()
{
    esp_sleep_wakeup_cause_t wakeup_reason;
    wakeup_reason = esp_sleep_get_wakeup_cause();

    DEBUG_INFO_PRINTLN("\n=== WAKE-UP REASON ===");
    switch (wakeup_reason) {
    case ESP_SLEEP_WAKEUP_EXT0:
        DEBUG_INFO_PRINTLN("Wake-up: External signal using RTC_IO");
        break;
    case ESP_SLEEP_WAKEUP_EXT1: {
        uint64_t wakeup_pin_mask = esp_sleep_get_ext1_wakeup_status();
        DEBUG_VERBOSE_PRINT("Wake-up: Button press on GPIO ");
#if DEBUG_LEVEL >= DEBUG_VERBOSE
        if (wakeup_pin_mask != 0) {
            int pin = __builtin_ctzll(wakeup_pin_mask);
            DEBUG_VERBOSE_PRINTLN(pin);
        }
#else
        (void)wakeup_pin_mask; // Suppress unused variable warning
#endif
        break;
    }
    case ESP_SLEEP_WAKEUP_TIMER:
        DEBUG_INFO_PRINTLN("Wake-up: Timer (scheduled update)");
        break;
    case ESP_SLEEP_WAKEUP_TOUCHPAD:
        DEBUG_INFO_PRINTLN("Wake-up: Touchpad");
        break;
    case ESP_SLEEP_WAKEUP_ULP:
        DEBUG_INFO_PRINTLN("Wake-up: ULP program");
        break;
    case ESP_SLEEP_WAKEUP_GPIO:
        DEBUG_INFO_PRINTLN("Wake-up: GPIO (legacy)");
        break;
    case ESP_SLEEP_WAKEUP_UART:
        DEBUG_INFO_PRINTLN("Wake-up: UART");
        break;
    case ESP_SLEEP_WAKEUP_WIFI:
        DEBUG_INFO_PRINTLN("Wake-up: WiFi");
        break;
    case ESP_SLEEP_WAKEUP_BT:
        DEBUG_INFO_PRINTLN("Wake-up: Bluetooth");
        break;
    case ESP_SLEEP_WAKEUP_UNDEFINED:
        DEBUG_INFO_PRINTLN("Wake-up: Undefined");
        break;
    default:
        DEBUG_INFO_PRINTLN("Wake-up: Power on / Reset");
        break;
    }
    DEBUG_INFO_PRINTLN("=======================\n");
}
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

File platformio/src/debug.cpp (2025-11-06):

#if defined(DEBUG_DISPLAY) && !defined(PIO_UNIT_TESTING)

#include "calendar_display_adapter.h"
#include "calendar_wrapper.h"
#include "config.h"
#include "display_manager.h"
#include "error_manager.h"
#include "littlefs_config.h"
#include "localization.h"
#include "version.h"
#include "weather_client.h"
#include "wifi_manager.h"
#include <Arduino.h>
#include <Fonts/FreeMonoBold9pt7b.h>
#include <LittleFS.h>
#include <WiFi.h>
#include <WiFiClientSecure.h>
#include <assets/fonts.h>
#include <assets/icons/icons_32x32.h>
#include <assets/icons/icons_48x48.h>
#include <assets/icons/icons_64x64.h>
#include <string.h>
#include <sys/time.h>
#include <time.h>
#include <vector>

// Display layout constants (for old layout compatibility)
#define CALENDAR_START_X 10
#define CONTENT_START_Y  60
#define EVENTS_START_X   400
#define OLD_EVENTS_WIDTH 390

// Global objects
DisplayManager display;
WiFiManager wifiManager;
CalendarManager* calendarManager = nullptr;
WeatherClient* weatherClient     = nullptr;
LittleFSConfig configLoader;

// Function declarations
void showMenu();
void processCommand(String command);
void testFullScreenError();
void testWifiConnection();
void testIconDisplay();
void testBatteryDisplay();
void testCalendarFetch();
void testErrorLevels();
void testDithering();
void clearDisplay();
void testWeatherFetch();
void testLittleFSConfig();
void helloWorld();
void testDisplayCapabilities();
std::vector<CalendarEvent*> generateMockEvents();
WeatherData generateMockWeather();
int getBatteryPercentage(float voltage); // Battery percentage calculation

void onDeviceBusy(const void*) {
    // Handle device busy state
    // Serial.println("Display is busy...");
}

void setup() {

    Serial.begin(115200);
    while (!Serial.isConnected()) {
        delay(10);
    }

    delay(1000); // Wait for serial connection

    esp_log_level_set("*", ESP_LOG_DEBUG); // Set ESP32 core log level to DEBUG

    Serial.println("\n\n=================================");
    Serial.println("ESP32 Calendar Display - DEBUG MODE");
    Serial.println("Version: " + getFullVersionString());
    Serial.println("=================================\n");

    // Initialize configuration from LittleFS for initial setup
    Serial.println("Initializing configuration...");
    if (!configLoader.begin()) {
        Serial.println("Failed to initialize LittleFS! Using built-in defaults.");
    } else {
        if (!configLoader.loadConfiguration()) {
            Serial.println("Failed to load configuration! Using built-in defaults.");
        } else {
            Serial.println("Configuration loaded successfully");
        }
    }

    pinMode(EPD_CS, OUTPUT);
    pinMode(EPD_RST, OUTPUT);
    pinMode(EPD_DC, OUTPUT);

    // Initialize display
    display.init();

    if (display.pages() > 1) {
        delay(100);
        Serial.print("pages = ");
        Serial.print(display.pages());
        Serial.print(" page height = ");
        Serial.println(display.pageHeight());
        delay(1000);
    } else {
        Serial.println("Single page display detected");
    }

    // display.display.epd2.setBusyCallback(onDeviceBusy); // Disable busy callback for debug
    display.clear();
    display.refresh(false);

    Serial.println("\nDEBUG_DISPLAY mode active - Normal operation bypassed");

    // Initialize WiFi client for calendar and weather testing
    WiFiClientSecure* wifiClient = new WiFiClientSecure();
    wifiClient->setInsecure();
    calendarManager = new CalendarManager();
    calendarManager->setDebug(true);
    weatherClient = new WeatherClient(wifiClient);

    showMenu();
}

void loop() {
    if (Serial.available()) {
        String command = Serial.readStringUntil('\n');
        command.trim();
        processCommand(command);
    }
    delay(100);
}
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

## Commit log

2025-10-20 fixed some styling issues
    [display_manager.cpp, display_manager.h, version.h]
2025-10-26 check battery before update
2025-10-26 reset button
2025-11-01 ics parser refactoring
    [partitions_custom.csv]
2025-11-10 readme and screenshots
    [esp32-calendar.3mf]
2025-11-10 kicad schematics
    [esp32-calendar.kicad_pcb, esp32-calendar.kicad_sch]
2025-11-10 added fritzing schematics, updated schematics
    [esp32-calendar.fzz, esp32-calendar.kicad_sch]
2025-11-10 back frame snapshot
2025-11-11 updated license
    [esp32-calendar.kicad_sch]
2025-11-12 renamed assets folder
    [esp32-calendar.3mf]
2025-11-19 added ability to specify multiple update hours, added millivolts display in the statusbar
2026-04-26 bugfix when daylight saving hour changes + other fixes
    [config.h, main.cpp]
